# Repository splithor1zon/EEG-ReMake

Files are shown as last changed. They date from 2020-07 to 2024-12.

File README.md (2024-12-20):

# EEG-ReMake

*Accepting suggestions, just create a new issue.* 🤝

This project is based on work of OpenEEG project and Olimex's implementation of it. This project is free to use, but is bound by Creative Commons Attribution-Sharealike license. More info can be found at: <http://openeeg.sourceforge.net>

## Photos

For photos refer to [/img/README.md](/img/README.md)

## Schematics

The schematic and design files are in Autodesk Eagle file-formats. Inspired by: <https://www.olimex.com/Products/EEG/OpenEEG/EEG-SMT/>

## Documentation

I translated the original documentation and format shifted it to markdown. Documentation content list:

1. [Introduction](./doc/0_introduction.md)
1. [Theory](./doc/1_theory.md)
1. [Goals](./doc/2_goals.md)
1. [Methodology](./doc/3_methodology.md)
1. [Results](./doc/4_results.md)
1. [Discussion](./doc/5_discussion.md)
1. [Conclusion](./doc/6_conclusion.md)
1. [Literature](./doc/7_literature.md)

Please mind that this was a high school project and the documentation is not highly sophisticated. But I hope it will be of interest to you.

## The goal

The goal of this project was to customize EEG-SMT by Olimex and design electrodes producable in school environment. I tried to keep expandability of this system open by introducing few new connectors.

## Not perfect

This design definitely has its flaws, but it was tested and proved working. Using eye closing test while measuring at occipital lobe produced apparent alpha wave increase:

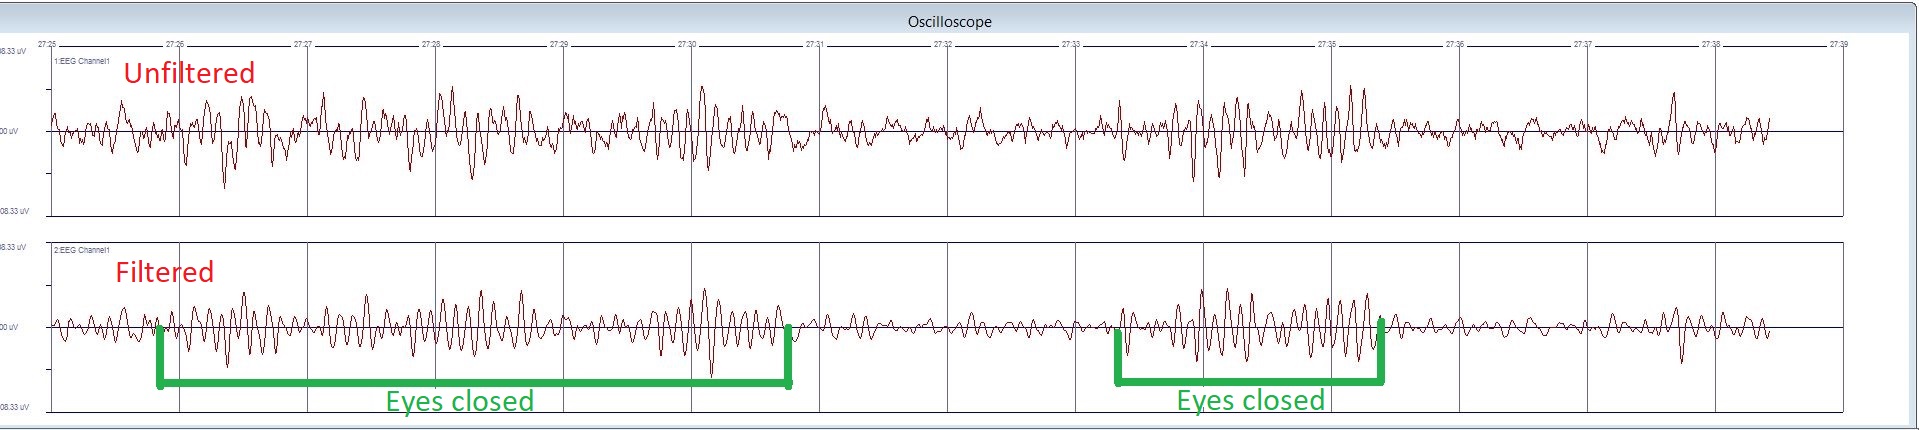
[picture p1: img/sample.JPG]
brainwave_recording Brainwave recording


## Software

As for software, I used open-source project BrainBay, which can be found here: <http://www.shifz.org/brainbay/>

## Finished Product

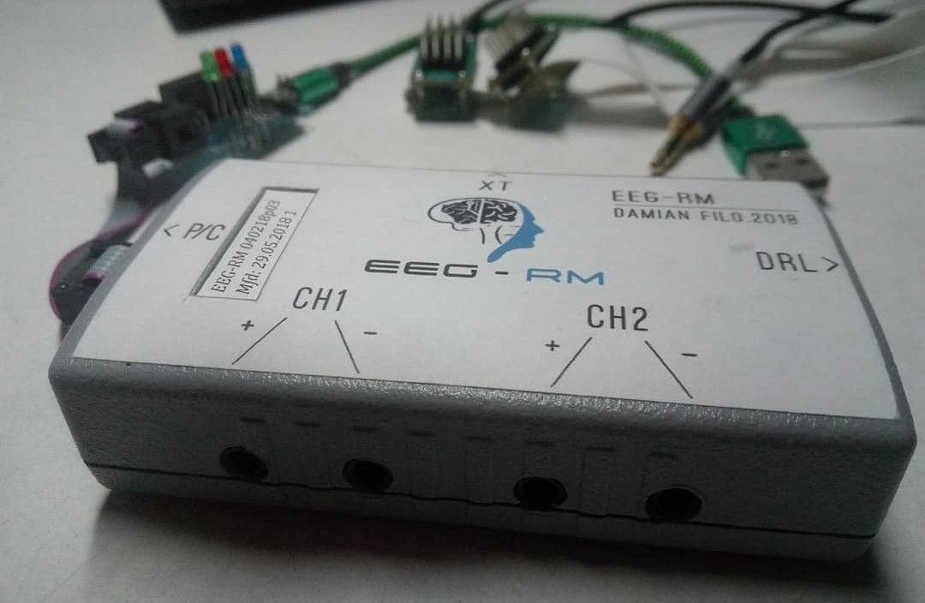
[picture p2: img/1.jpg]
Final assembly


I can also provide some guidelines on the final assembly.

## Interview about this project

<https://vedanadosah.cvtisr.sk/eeg-ako-studentsky-projekt>

Hopefully this project will help somebody. 🤗

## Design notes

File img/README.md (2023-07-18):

# Photos
Bare electrode pcb.
Active amplification electrode circuit. Assembled.
Both parts of an active electrode.
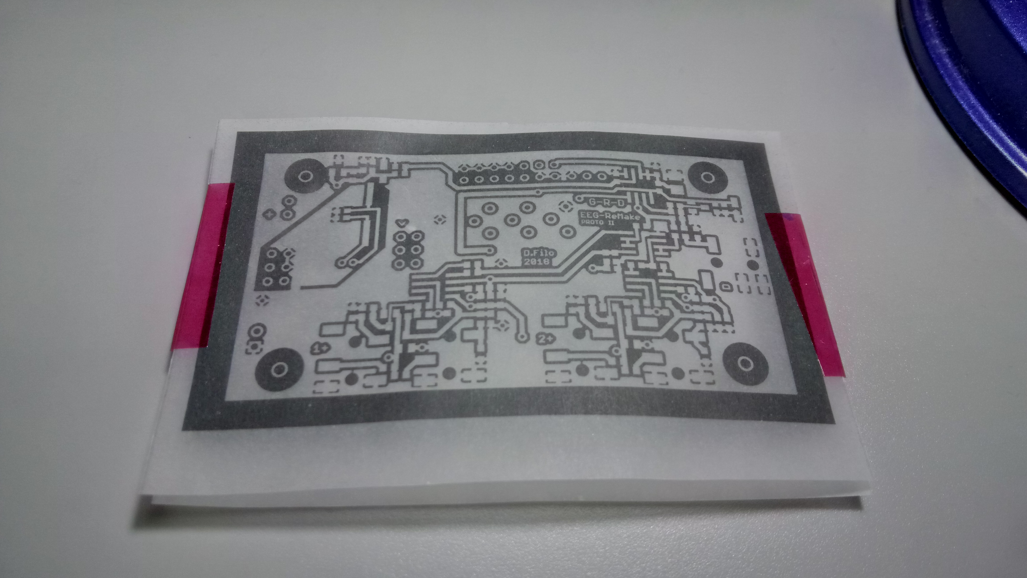
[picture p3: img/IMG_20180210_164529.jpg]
Negative of circuit board design. Blocks UV light.

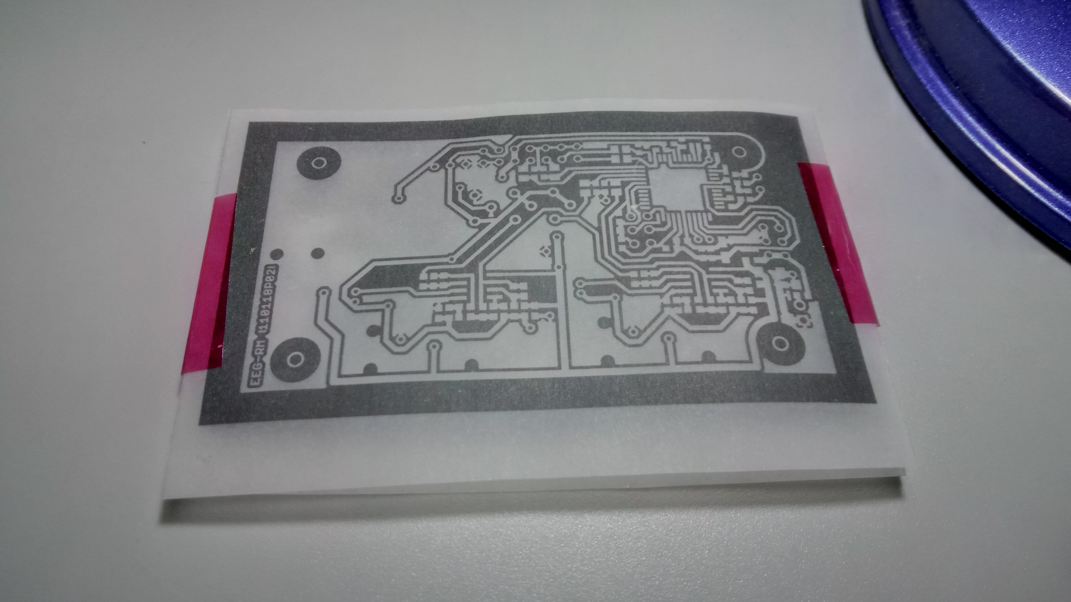
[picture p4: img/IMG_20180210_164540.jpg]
Negative of circuit board design. Blocks UV light. Other side.

Active electrode pair with rubber band head strap.
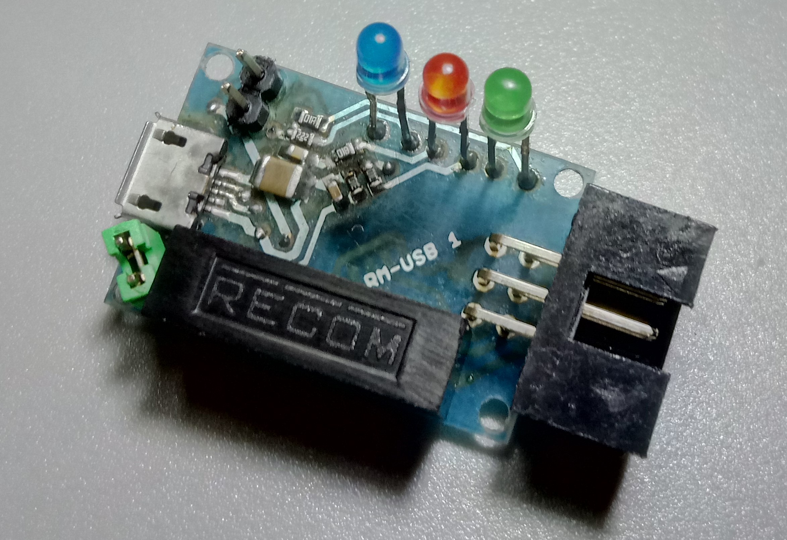
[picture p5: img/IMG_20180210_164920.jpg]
Isolated USB to UART controller. Also supplies power to the board.

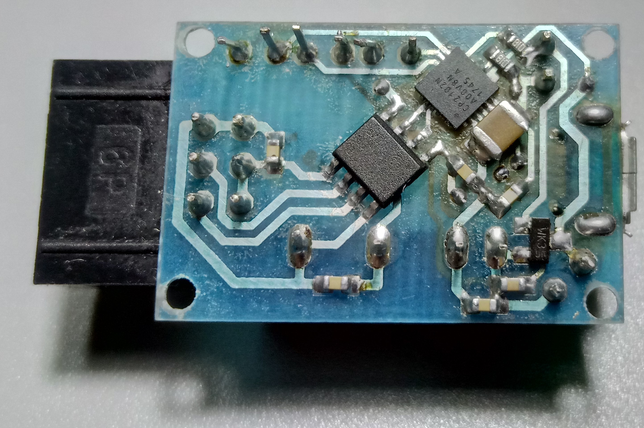
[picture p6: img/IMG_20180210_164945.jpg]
Isolated USB to UART controller. Also supplies power to the board. Other side.

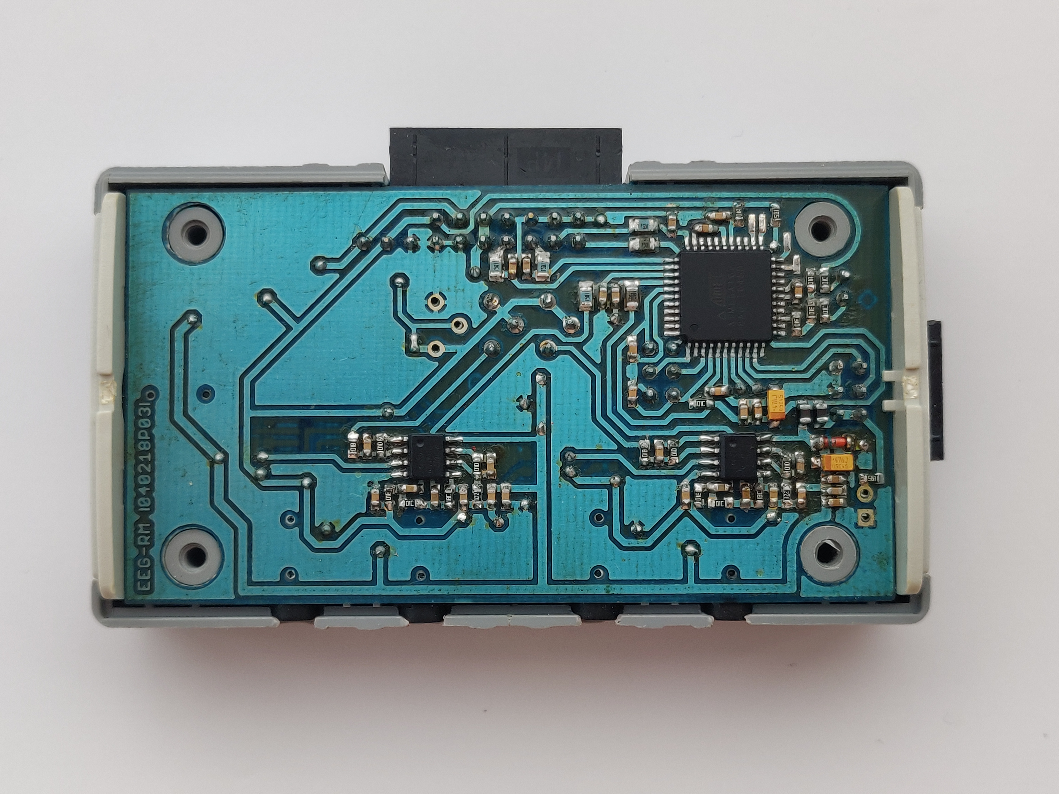
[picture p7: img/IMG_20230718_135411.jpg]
EEG board. MC side.

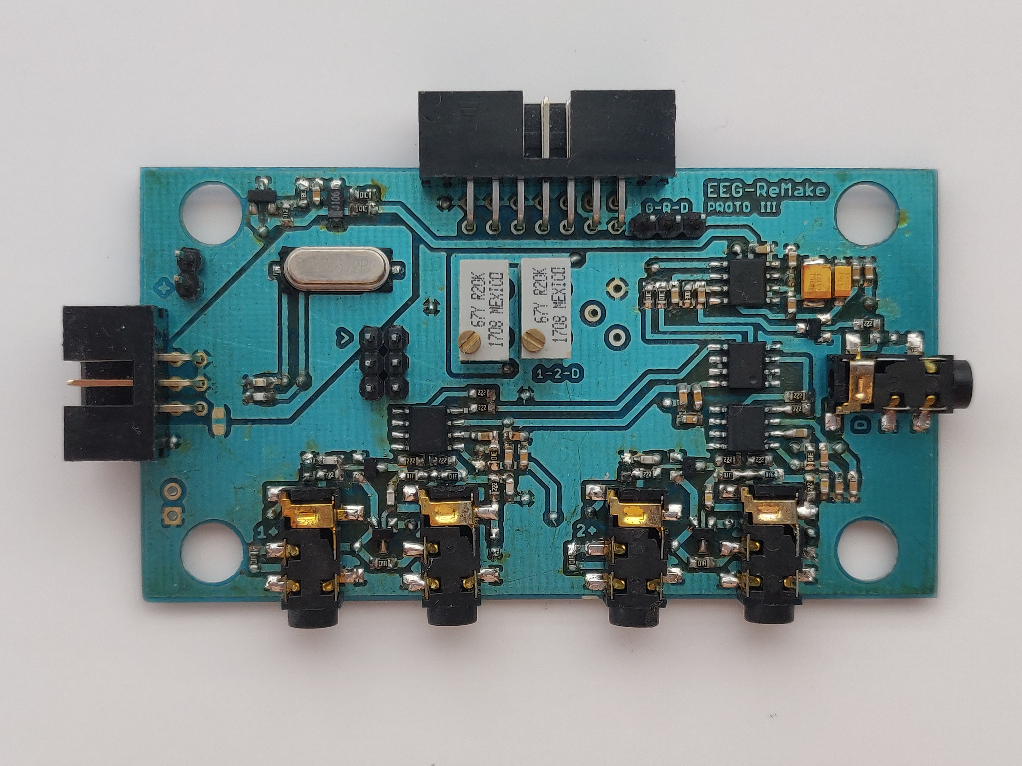
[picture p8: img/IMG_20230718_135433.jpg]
EEG board. Front side.


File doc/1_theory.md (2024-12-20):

# Theory

The electroencephalogram is at first sight a complex device, but its principles are quite simple. The average person does not encounter it every day, so it is necessary to describe the theory in detail. We should start nicely from the beginning.

## Human body (brain)

The human body, as it is known, is essentially one big electrochemical cell. It uses electrical impulses to move muscles and transmit information. Although scientists have been studying it for many centuries, it is still not understood how many things work; we can sometimes only speculate about the function of some of the components of this complex machine.

As the most important organ of our body, some of the brain's functions remain undiscovered. However, the brain is not "only" important in keeping our body alive, it houses our consciousness; without the brain as a control processor, our body would not know what to do and would be inactive. Of course it maintains important life functions, but with medical advances it is possible to keep a person alive even without brain function. In our opinion, it will not be long before the world will witness the first brain or head transplants.

Just as the whole body works on the electrochemical principle, the brain stores our memories, perceives through the senses and processes all information in the same way. While chemical reactions would be difficult for us to measure and ascertain their purpose, electricity can be manipulated by mankind in a rather advanced way. We owe the fact that we can pick up these electrical impulses in a non-invasive way to the relative conductivity of our bodies.

The number of nerve cells in the brain is estimated to be 10^11; cortical neurons are strongly interconnected. The surface of a neuron can be covered with up to 1000-100,000 synapses (the point of connection with other neurons). The resting voltage is around -70 mV and at peak action the potential is positive. The amplitude of the nerve impulse is about 100 mV and lasts about 1 ms.

## EEG

The first recording of the electric field of the human brain was demonstrated by the German psychiatrist Hans Berger in 1924 in Jena. He named the recording the electroencephalogram (EEG). From 1929 to 1938 he published 20 scientific papers on the EEG under the same title "Über das Elektroenkephalogram des Menschen".

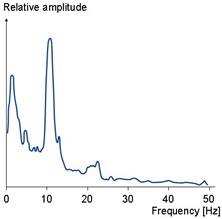
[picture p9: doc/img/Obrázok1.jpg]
"Brainwave amplitude at individual frequencies" Brainwave amplitude at individual frequencies


EEG can sense three kinds of brain activity:

1. Spontaneous activity
2. Evoked potentials
3. Bioelectrical events of individual neurons

**Spontaneous activity** is measured on the scalp "non-invasively" or on the surface of the brain "invasively". The EEG amplitude is approximately 100 μV when measured on the scalp and approximately 1 to 2 mV when measured on the surface of the brain. The bandwidth of this signal is from 1 Hz to ~50 Hz. However, individual frequencies have different amplitudes; Figure 1-1 shows the relative amplitude to each frequency. As the phrase "spontaneous activity" implies, this activity continues uninterrupted throughout a person's life.

**Evoked potentials** are those components of the EEG that arise in response to a stimulus (which may be electrical, auditory, visual, etc.). Such signals are usually below the noise level and are therefore not easily distinguishable, and it is necessary to use a large number of stimuli and signal averaging to improve the signal-to-noise ratio.

**Single neuron events** can be studied using microelectrodes that are injected into the cells of interest. Through single-cell studies, we hope to create models of cellular networks that reflect the true properties of brain tissues.

### Electrode placement

We usually use the internationally standardised 10-20 system to record spontaneous activity. In this system, 21 electrodes are placed on the surface of the scalp, as shown in Figure 1-2. The positions are determined as follows: the reference points are the "nasion," which is located at the top of the nose, level with the eyes; and the "inion," which is essentially a bony lump at the base of the skull on the midline of the back of the head.

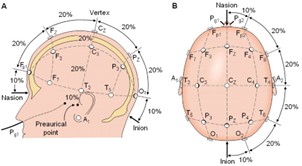
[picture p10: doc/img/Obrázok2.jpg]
"The 10-20 system" The 10-20 system


From these points the circumference of the skull is measured in the transverse and median planes. The location of the electrodes is determined by dividing these circumferences into 10% and 20% sections. Three additional electrodes are placed on each side equidistant from adjacent points, as also shown in the figures.

In addition to the 21 electrodes of the international 10-20 system, the 5-10 system, which uses a denser arrangement, is also used. There are also many other electrode systems for recording electrical potentials on the scalp. The "Queen Square" electrode placement system has been proposed as the standard for recording built-up potentials in clinical trials.

Bipolar or unipolar electrodes can be used in EEG measurements. With bipolar, the potential difference between the two electrodes is recognized. In the latter method, the potential of each electrode is compared with either the neutral electrode or the average of all electrodes.

"The difference between unipolar and bipolar EEG" The difference between unipolar and bipolar EEG

### The sources of EEG signal

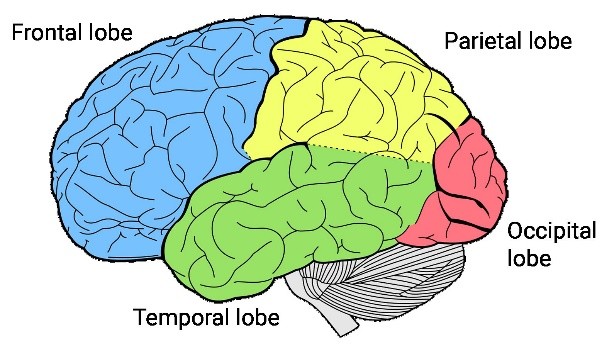
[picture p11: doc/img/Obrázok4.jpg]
"Brain lobe locations" Brain lobe locations


In the figure above you can see how our brain is divided into different sectors. Thus, when the EEG senses the time course of electrical activity generated by the brain, we can capture specific waves of our interest because we know approximately which areas of the brain are responsible for processing information at any given time:

**Occipital lobe** - This part of the brain is mainly responsible for processing visual information. It is usually where we measure the reception of visual stimuli (video, pictures).

**Parietal lobe** - The parietal lobe is very important in processing sensory information from different parts of the body, knowledge of numbers and their relationships, and manipulation of objects. Its function is also to process information related to the sense of touch. A part of the temporal lobe deals with spatial vision.

**Temporal lobe** - The temporal lobe has external parts that are responsible for language processing and speech production. The inner regions are more active during spatial navigation. You may have heard of the hippocampus: This is the brain region in the temporal lobe where we form spatial and autobiographical memories from, for example, early childhood days. It is also referred to as the primary area for auditory processing.

**Frontal lobe** - The frontal part of the human brain is enlarged compared to other mammals. Basically, the frontal cortex is in charge of cognitive control: it keeps us from running after flashing lights, forces us to complete studies, and connects different memories and experiences into a consistent whole. In other words, we are able to move voluntarily thanks to it, to make simulations of the future and simulations of the consequences of our actions (to decide between good and evil).

### The structure of EEG signal

In addition to the area characteristics from which certain electrical activity originates, we can also analyze which frequencies drive the ongoing activity. Whenever our brain is in a certain state, the frequency patterns change.

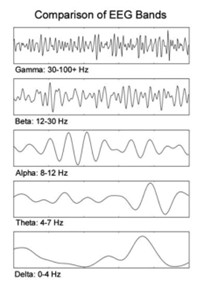
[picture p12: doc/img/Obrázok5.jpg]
"Comparison of EEG bands" Comparison of EEG bands


**Delta δ (1-4 Hz)** - In sleep labs, delta waves are studied to assess the depth of sleep. The stronger the delta rhythm, the deeper the sleep. Interestingly, delta waves are only present in non-REM (Rapid Eye Movement) phases - when we are not dreaming, for example.

**Theta θ (4 - 8 Hz)** - Theta is associated with a wide range of cognitive processes, such as encoding and memory retrieval, but it depends on the area.

**Alpha α (8 - 12 Hz)** - Alpha waves can be observed mainly when relaxing with eyes closed. EEG training often uses alpha waves to monitor relaxation.

**Beta β (12 - 25 Hz)** - Commonly seen in people with normal waking consciousness. In motor areas, beta frequencies become stronger when we perform or plan to perform movements of any part of the body. Interestingly, this increase in beta is also noticeable when we observe other people's body movements. Our brains seemingly mimic the movements of their limbs, suggesting that there is a complex "mirror neuron system" in our brains that is coordinated by beta frequencies.

**Gamma γ (>25 Hz, typically 40 Hz)** - Currently the gamma frequencies are the black holes of EEG research. Some researchers argue that gamma reflects strong concentration and serves as a carrier frequency to facilitate data exchange between brain regions. Others associate gamma with rapid eye movements, the so-called "microsaccades," which are thought to be essential parts for sensory processing and information capture.

EEG also has a great use in medicine, mainly because it can detect epileptic seizures that whether a person is susceptible. EEG in epileptic seizure records unambiguous regular pulses with high amplitude, as you can see in the picture. However, we know many types of epilepsy and their EEG may look different, however most of the time it is easily detectable.

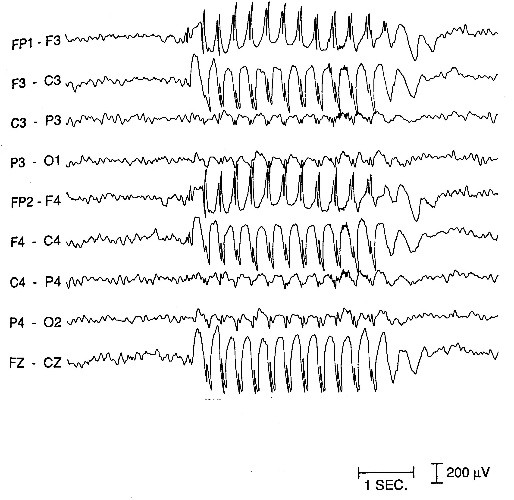
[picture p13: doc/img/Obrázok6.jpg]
"EEG during epileptic seizure" EEG during epileptic seizure


## Hardware

Electroencephalographic measurements use a recording system consisting of:

- electrodes (usually with conductive media)
- amplifiers and filters
- A/D converter
- recording equipment

The electrodes read the signal from the surface of the head, the amplifiers transmit the microvolt signals to a range where they can be accurately digitised, the transducer converts the signals from analogue to digital form, and personal computers (or other relevant equipment) store, process and display the acquired data. The amplifiers with filters and the A/D converter are usually housed in a single device called a BCI (Brain-Computer Interface). The main intention of this work is to create this device.

The best way to explain this is to use the device itself, so I give examples of the components we will use, although there are many other variations.

### Electrodes

In our device, we will use so-called active electrodes, which, because they amplify the signal as soon as it is recorded, will not be so susceptible to signal interference on the way to the amplifier. We don't have to worry that the electrodes will be big because of this, of course they will be bigger than passive electrodes, but with a low number of channels it doesn't matter at all. Our EEG will be expandable up to 6 channels in a bipolar circuit, that means 12 electrodes plus 1 DRL for connection. This is a decent expandability in our opinion. The active electrodes we will make will be only 14x22mm, will be able to penetrate through the hair directly to the skin using pins, and can also be clamped on a rubber band for attachment to the head. Active electrode construction developed by us:

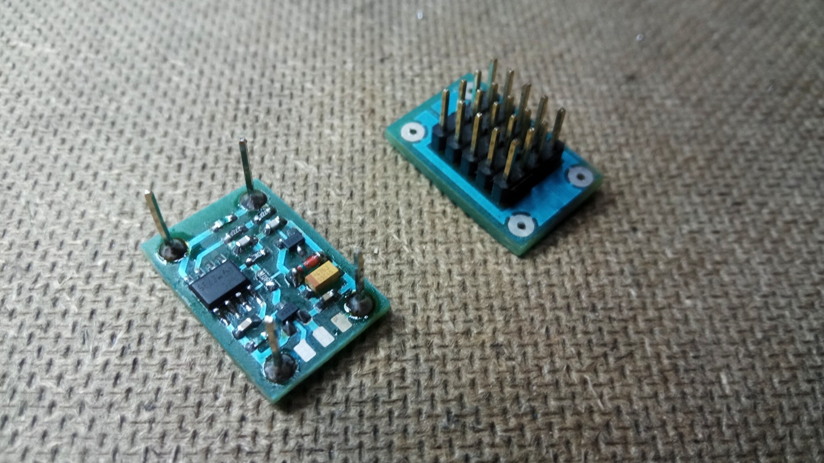
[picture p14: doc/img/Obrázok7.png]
"Active electrode with contact and active part" Active electrode with contact and active part


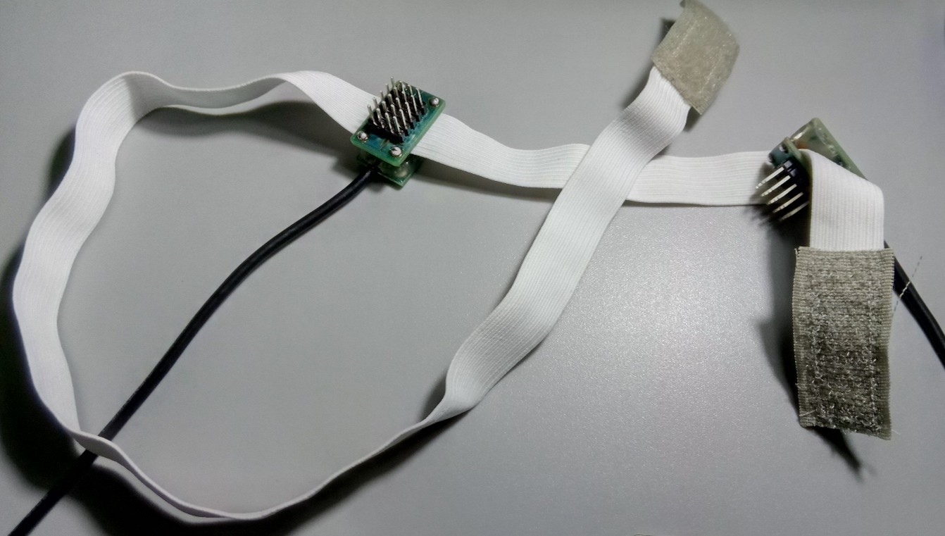
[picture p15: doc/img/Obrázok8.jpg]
"Assembled pair of electrodes with head strap" Assembled pair of electrodes with head strap


The DRL (Driven Right Leg) electrode is very important because it picks up a reference signal from some neutral location on our body and subtracts the recorded signal from all channels. This way we largely eliminate interference from the surroundings and our own body. The DRL electrode must be passive because the use of an active electrode would not allow it to function properly. Reference DRL wiring:

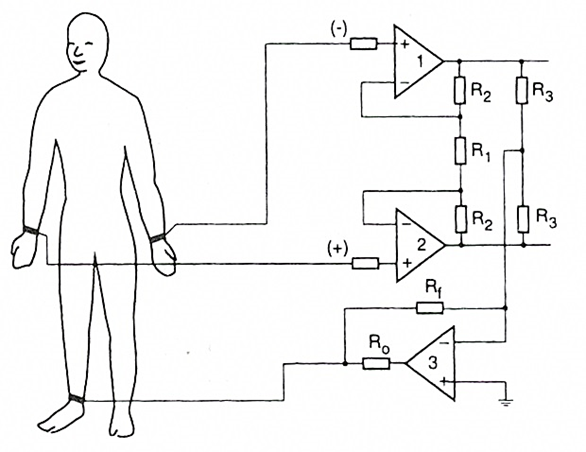
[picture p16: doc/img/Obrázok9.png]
"DRL electrode design" DRL electrode design


The length of the electrode cable is critical at such small voltages, generally a length of around one metre is recommended for the device we make. We use 3.5mm jacks to connect the electrodes to the BCI, but this is specific to each type of device separately.

### Amplifiers and filters

The first amplification stage in our device is located at the active electrodes. The captured and slightly amplified signal then travels to the instrument itself, where it is the turn of the instrumentation amplifier, which is basically several operational amplifiers specially interconnected in one package. It has a dual function, to read out the captured signal of the DRL electrode and to accurately amplify the as yet very weak signal.

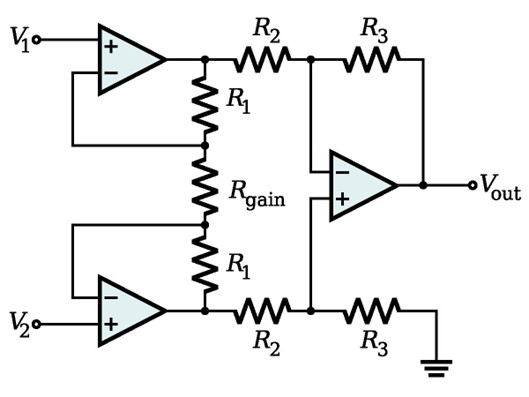
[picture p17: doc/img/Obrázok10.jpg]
"Instrumentation amplifier diagram" Instrumentation amplifier diagram


Next comes the dual operational amplifier, which also performs a dual function. The first serves as a trimmer-adjustable gain control to calibrate the signal amplitude. The second serves as a third-order Bessel-type low-pass filter, i.e. it "cuts off" all frequencies above 152Hz. This is a very beneficial effect, since we need frequencies in the 1-50Hz range and all other frequencies are simply interference. Interference from either the mains or other electronic equipment is usually removed or attenuated by the DRL system already in use.

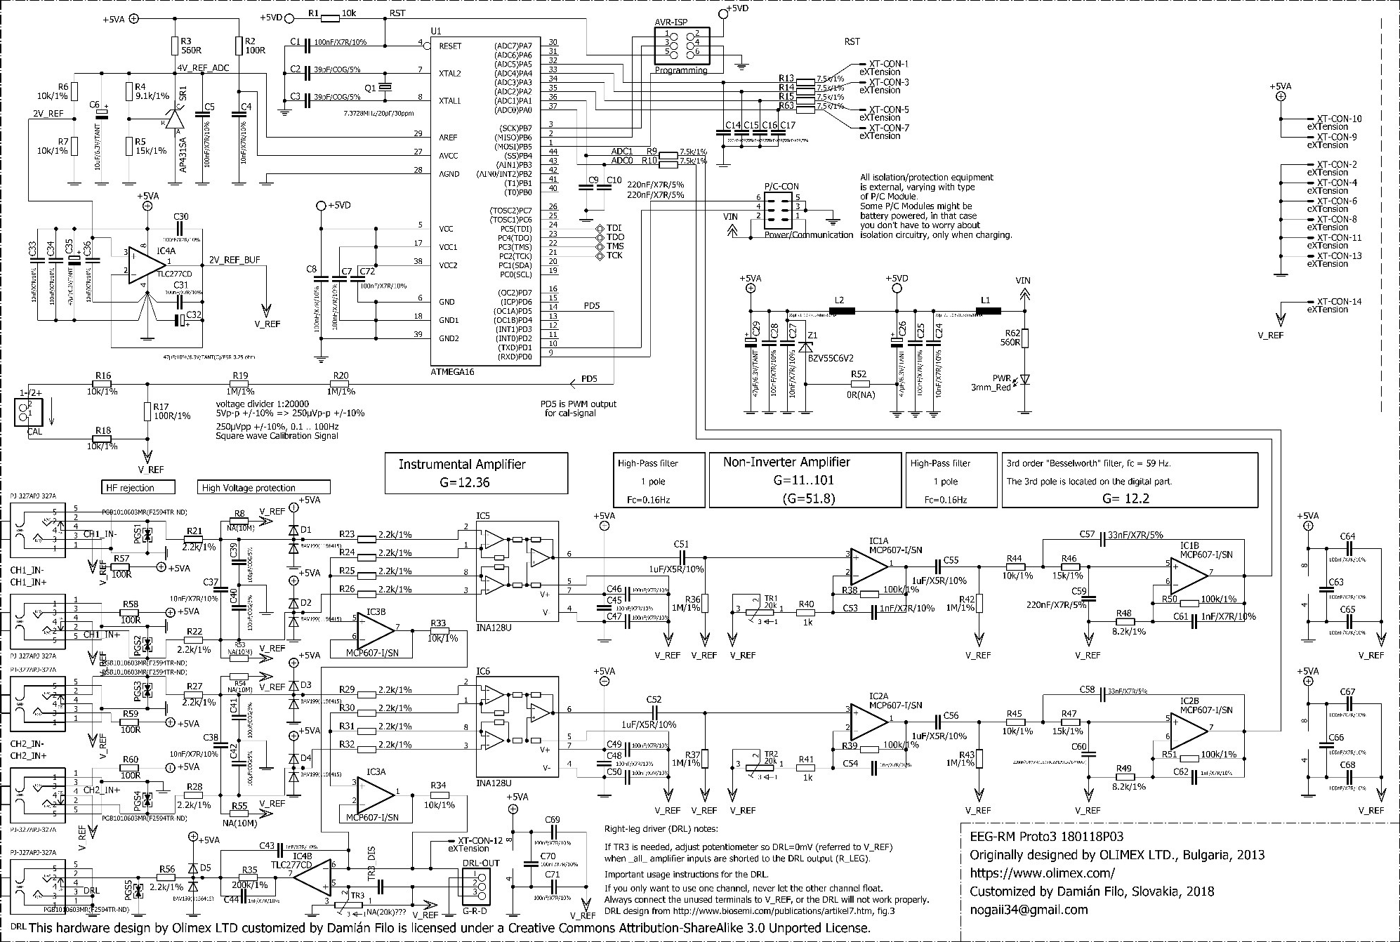
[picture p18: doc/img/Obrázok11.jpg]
"EEG circuit scheme" EEG circuit scheme


The basic gain after all these stages should be G=7812.5, which can be further tuned. The passband filter should be in the range 0.16-152Hz.

### A/D converter

It is an integral part of the whole device that allows us to view, record and edit the signal on digital devices, not just on the oscilloscope. The output from the amplifier cascade terminates on one of the pins of the A/D converter, in this case in the form of an ATMega16 microprocessor. We use a sampling resolution of 10 bit i.e. 1024 possible values on a 0-4V scale. This, after subtracting the gain, gives a range at the input of 512µV at 0.5µV resolution. Since the captured signal is in the region of 100µV this is adequate.

### Recording device

Once the signal has been successfully digitised, we need to send that data on for processing. The best way to do this would be to use a universal form of connection to computing and what is more universal than a universal serial bus (USB).

The ATMega16 microprocessor somehow does not support USB connectivity, but it can send data via UART (universal serial communication). Although UART is not directly compatible with USB, there are a number of chips from different manufacturers that can interconnect them. I decided to go the modern route and use the latest chips from Silicon Labs. The CP2102N chip offers more than enough data throughput, a wide range of features in a small form factor and at a reasonable price. Reliability was also a critical factor.

However, since we decided to use power directly from the USB interface, it is necessary to isolate our device from the surrounding environment for safety. We achieved this by using an isolation 5V-5V DC-DC converter for the power supply and a chip to isolate the data connection also from Silicon Labs.

Due to the modularity of our device, this USB/UART converter will be able to be used in applications other than EEG. The reverse is also true, it is possible to create arbitrary interfaces using e.g. Bluetooth technology, where we ensure complete isolation from the environment when powered by the battery.

Thanks to the IDC connectors used, modularity is easy, no special connectors, all one needs to know is the pin layout.

### Software

We decided not to spend a lot of time on software because of the open-source solutions that already exist. However, that doesn't mean we don't need to spend time on it at all. We plan to create simple software in the future designed to control the EEG power supply.

We will use "BrainBay" as the main program to display and process the EEG data. But in general, we can use any program supporting OpenEEG packet composition version 2. The interface of this program is quite simple and user-friendly. It supports signal acquisition from multiple sources and a wide range of modifications to these signals. On the output we can display a digital oscilloscope, frequency analyzer, MIDI synthesizer, visualization, various graphs, columns and much more. This program also supports logging of the acquired data.

[Next page](./2_goals.md)

*Translated by DeepL.*

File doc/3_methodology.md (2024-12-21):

# Methodology

The methodology will be written in a way that any electronics enthusiast with more advanced knowledge and experience of PCB fabrication and component assembly can understand.

## Open-source licensing

We decided to go the route of an open source project, as it would have taken us months if not years of focus to build a schema from the ground up and test the wiring.

The OpenEEG project was exactly what we were looking for. Not only did a group of enthusiasts create a schema and a way to get involved, but they also created a community. While it's true that this project is older (~2005) and fewer and fewer people refer to this project, if we had a question about the project, there was always someone who could help us via email.

This project is licensed under a Creative Commons Attribution - ShareAlike license. This means that this project can be used and shared without restriction as long as the source is credited and the same license is used. I plan to share this iteration of the project once I have completed the design and schematic. Definitely sounds interesting to contribute to such a great community of enthusiasts. Hoping that our work will help someone who may be doing a similar vintage project, well that's the future...

Although we're not using the original ModularEEG project, but an iteration of it optimized for direct USB connectivity, compact size, and use of SMD components called EEG-SMT. I can and must stick to the original license. This iteration was made by Olimex Ltd, a Bulgarian company based in Plodiv, Bulgaria's second largest city. This company sells parts and finished electronic projects. And thanks to that license, it was necessary for them to also share their schematics and PCB designs, which we customized. The modified schematic:

"EEG circuit scheme" EEG circuit scheme

## Component selection

Since Olimex has access to a quasi-limitless amount of those specific parts, we didn't have that option. We used various sites as sources of parts, such as AliExpress for connectors and cables, where you can get such parts cheap and of good quality. For the rest of the functional parts (resistors, capacitors, integrated circuits...) we used the Mouser site, where they have a very wide selection and free shipping for orders over 50$. Later we had to reorder some parts through a friend because we made some changes in the design. The lesson learned was: Order only the final selection of parts, think carefully.

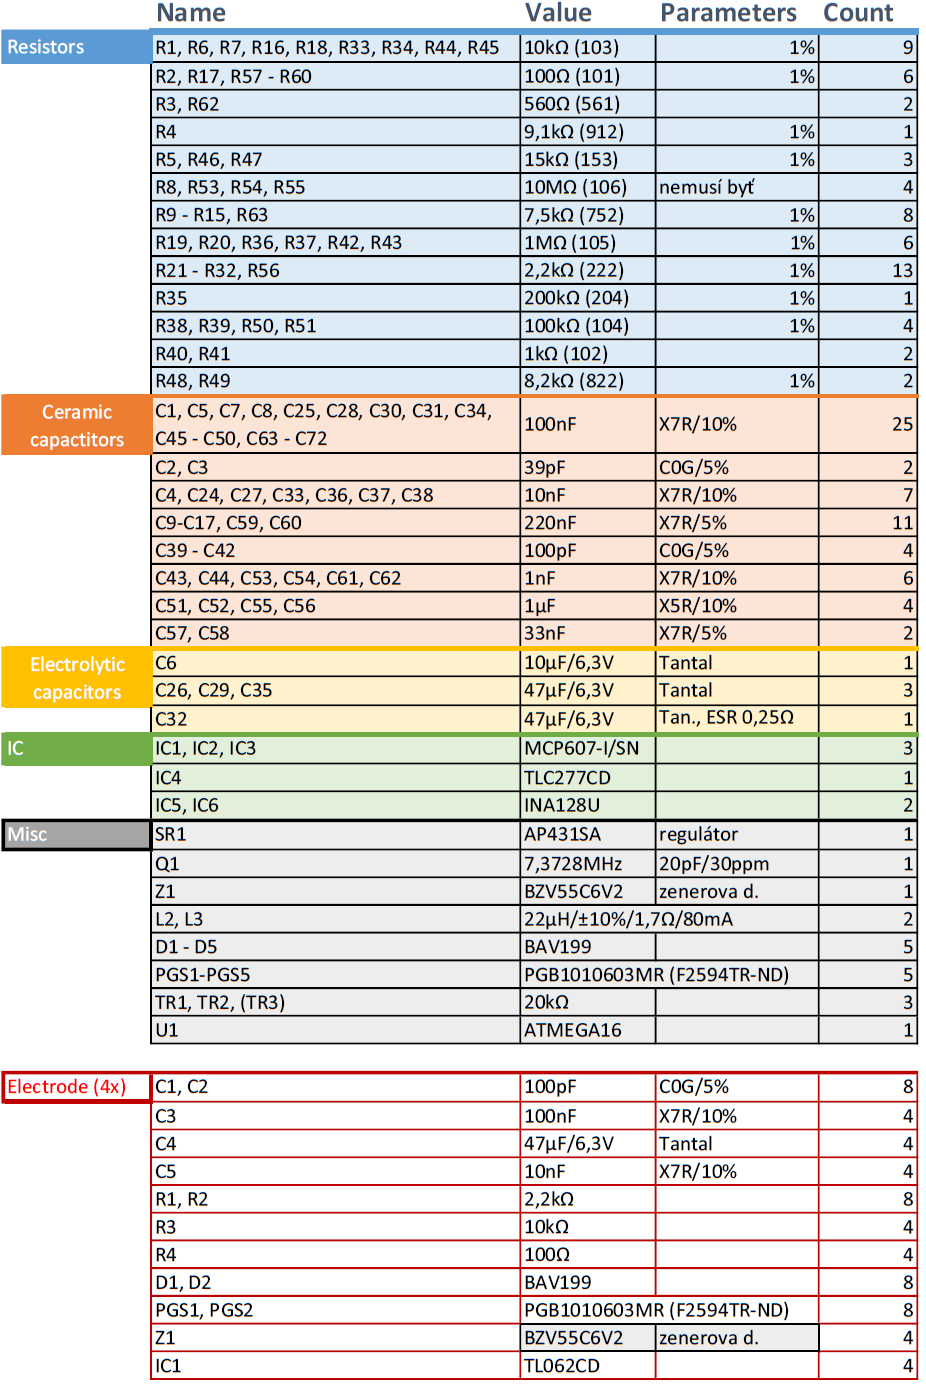
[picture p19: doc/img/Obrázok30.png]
"Component list"


## First prototype

This was our first experimental design on which we honed our skills with Eagle. It took us at least 3 weeks to modify the schematic and design the PCB. That's not counting the actual product. However, it was accompanied by a few complications, which fortunately were solved "painlessly". For etching I used a solution of hydrochloric acid and hydrogen peroxide.

The first complication was insufficient silver plating of the PCB, this translated into insufficient adhesion of tin to copper, which corroded due to the environment. Being silver plated, the tin spilled out seamlessly. Although there was a higher risk of a cold joint (electrically non-conductive), it was possible to solder all the components together.

The other not-so-big complication was using smaller SMD parts (0603) than I used in the design (0805). This had the effect of reducing the neatness of the PCB and making it more difficult to store and solder the components.

The third, rather unpleasant complication was the very imperfect etching, soldering and fixing of the MicroUSB connector located directly on the board. It had to be in a specific position for it to be used at all. Since Prototype 1 also had an IDC connector for power and communication, it was only meant at the time as an I/O for data and an output for power. Thus, MicroUSB held the main role of powering the circuits and had no data pins connected. Later, after re-evaluating the pros/cons, we decided to merge it with the IDC connector and thus called it Power/Communication Connector (P/C CON) to which the P/C Module connects. It acts as a power supply to the EEG and communication with surrounding devices (depending on the module used).

The fourth complication was the inexperience of programming ATmega microprocessors. When first programmed and connected to the computer, the EEG sent nonsensical data. Upon later discovery we found out that it only worked on an internal clock of 1MHz, This caused insufficient data processing speed and slow data sending. As we are using UART technology and within it we need to choose a fixed baud rate as a requirement for correct communication between devices. The crystal of unconventional frequency of 7.3728MHz guarantees the correct frequency of sending data through UART, where it is allowed to multiply/divide this frequency for our requirements. The simple solution to this awkward situation was to set the configuration fuses correctly during programming. This allowed us to activate the external crystal and use its frequency.

Although we were unable to test Prototype 1 with electrodes, due to the swapping of the power and signal pins in the jack used in the wiring in Prototype 2, overall Prototype 1 can be called a success. Its schematic, photos and design can be found as attachments. The design of the first prototype:

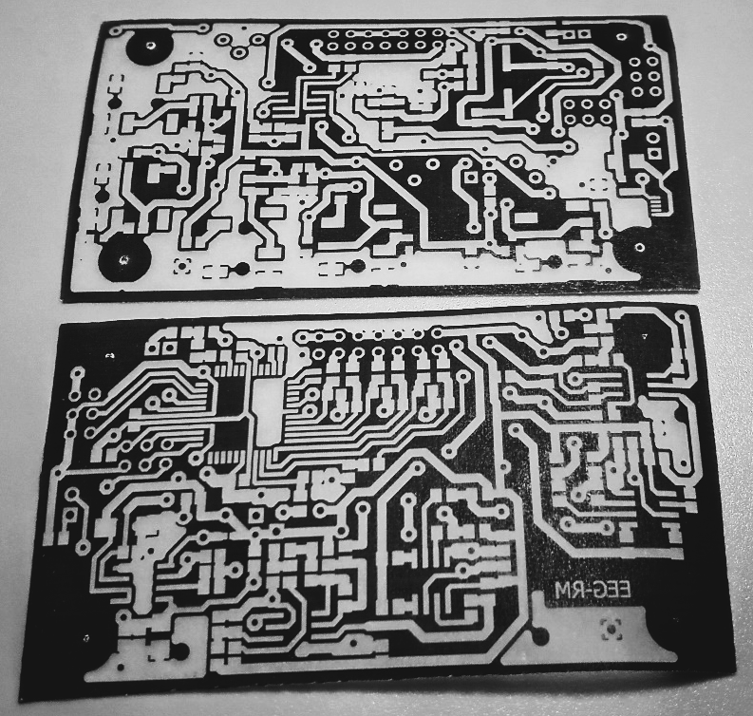
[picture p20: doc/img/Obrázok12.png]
"First prototype PCB design" First prototype PCB design


## Electrodes

The biggest challenge in designing the electrodes was figuring out their construction. We were very interested and inspired by the work of Jim Peters, who invented the design of electrodes with a contact surface consisting of pins. The pins allow the electrodes to be connected to the head even through the hair and the fact that they are also active makes it possible not to use a conductive gel, which can though still be beneficial. Olimex has provided a reliable and safe circuit design for these electrodes, however they only sell electrodes with a contact area directly on the gold plated surface, i.e. it is necessary to use a conductive gel for contact with the skin through the hair. We did not modify the electrode scheme in any way, but we did our own construction design and devised a method of firmly connecting the pins with the possibility of clamping the electrodes to a elastic band with Velcro for easy and firm fitting of the electrodes to the head.

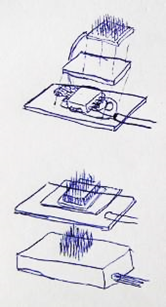
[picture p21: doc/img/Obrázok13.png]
"Jim Peters's electrode design" Jim Peters's electrode design


Our design of the active electrodes consists of two circuit boards, one designed explicitly for the pin connections and the other containing all the electronic components and pads for connecting the audio cable to the power supply for the operational amplifier and transmitting the signal to the EEG itself. These two PCBs are firmly soldered together using four solid brass pins located around the corners of these PCBs of identical size 14x22mm. Of these, one pin transmits the signal from the pins connecting to the skin to the other PCB where it is amplified and sent on.

"Active electrode with contact and active part" Active electrode with contact and active part

For easy placement on the rubber band, also easy movement on it and protection of electrical components we sealed the circuit with glue from a glue gun. This makes these electrodes the final product and suitable for use in any ModularEEG type EEG with the correct connection of the individual wires in the cable. The 3.5mm jack does not have to be used, but it is very suitable for this purpose, due to its widespread use, portability, reliability and above all the five pin female connection method, which I have only used in the third prototype. In short, it allows not to use all the electrodes while maintaining the correct functionality of the DRL, since the DRL needs to have all the electrodes connected to the body, they cannot remain unconnected (so called float). The usual method is to connect additional signal jumper cables to the V_REF virtual ground, however these female jacks allow automatic connection to this ground. Thus connecting when the electrode is not connected and of course disconnecting when the electrode is connected. The idea for this wiring was suggested to us by Stefan Jung, who emailed us asking for troubleshooting and understanding the functions of the various components of this particular EEG.

"Assembled pair of electrodes with head strap" Assembled pair of electrodes with head strap

The procedure for their manufacture is quite straightforward and can be found in pictorial form as an appendix. We would only note that you have to be careful about the rotation of the components as well as the PCBs, because they are not symmetrical and can only be joined together with one side, one direction. Also, we do not recommend a cable length greater than 1.2m, as in similar designs cables around 2m long have shown malfunctions that are incompatible with the correct function of the device.

## Second prototype

Overall, Prototype 2 is a very neat and professionally done design. In addition to the radically different placement of components, the swapping of pins in the electrodes, and the removal of the MicroUSB connector, there are changes such as bringing out the control pins for electrode calibration and for DRL connection configuration and diagnosis. Further, the dimensions of the PCBs were sized exactly to the components used, a better power cascade and ground polygon, lettering for easy identification of the brought out pins, female jacks and trimmers on the board, a reduction in the number of interconnects through the PCB, the product name changed from the original EEG-SMT to EEG-RM (ReMake), and a simple serial number consisting of the date and version of the prototype was added. The already etched clean unmounted PCB of the second prototype:

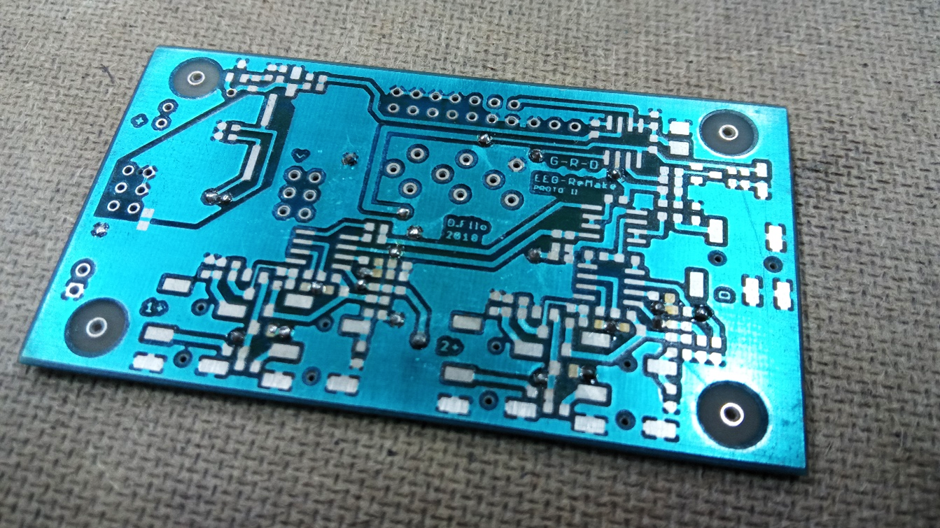
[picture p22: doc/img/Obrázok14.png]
"Front side of Prototype 2 PCB" Front side of Prototype 2 PCB


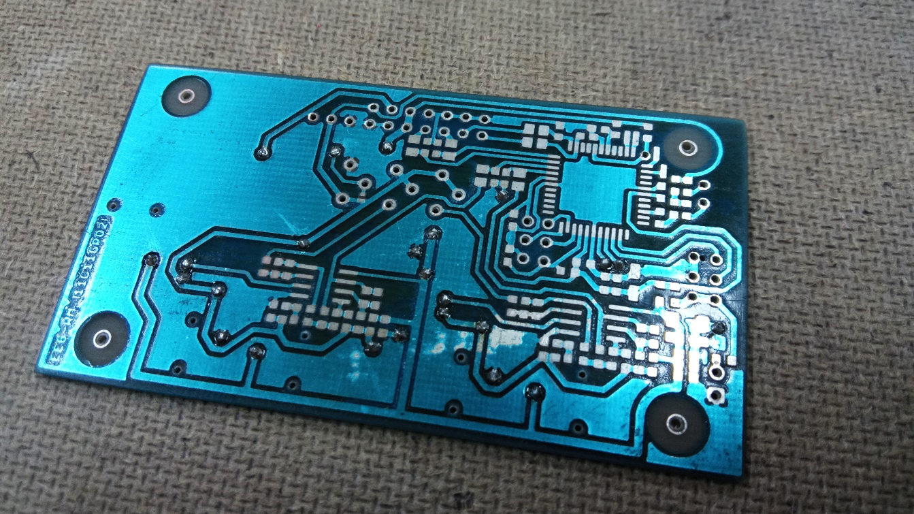
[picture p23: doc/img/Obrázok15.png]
"Back side of Prototype 2 PCB" Back side of Prototype 2 PCB


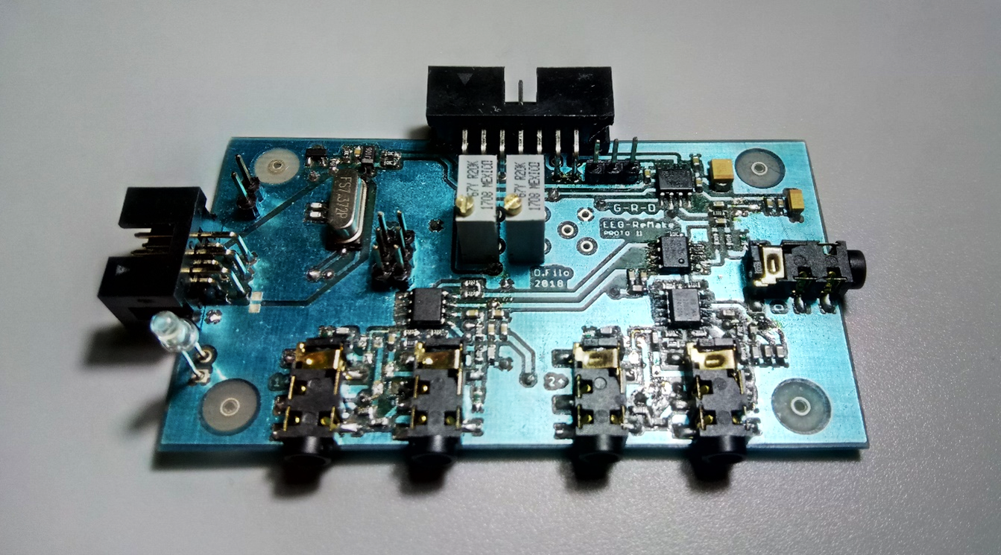
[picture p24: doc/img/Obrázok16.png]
"Front side of Prototype 2 PCB with components soldered on" Front side of Prototype 2 PCB with components soldered on


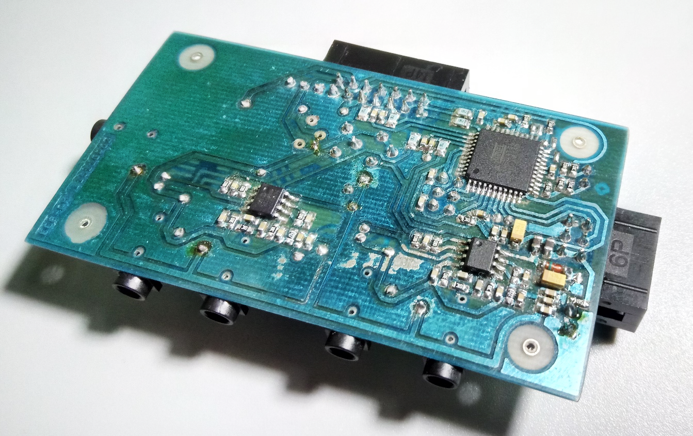
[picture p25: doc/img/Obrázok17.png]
"Back side of Prototype 2 PCB with components soldered on" Back side of Prototype 2 PCB with components soldered on


The big change was to combine the power and communication functions under one connector, the P/C connector. This original connection using the IDC 6pin connector allows you to create a set of P/C modules differing in the technologies used, power and isolation options under one universal connection method. We have placed emphasis on ensuring that incompatibilities do not arise in the future. In this way, compatibility is more or less guaranteed. Whether one uses wireless or conventional technology, as long as that technology can interpret UART, which is a very widespread and universal connection standard, there will be no problem with connectivity and application development.

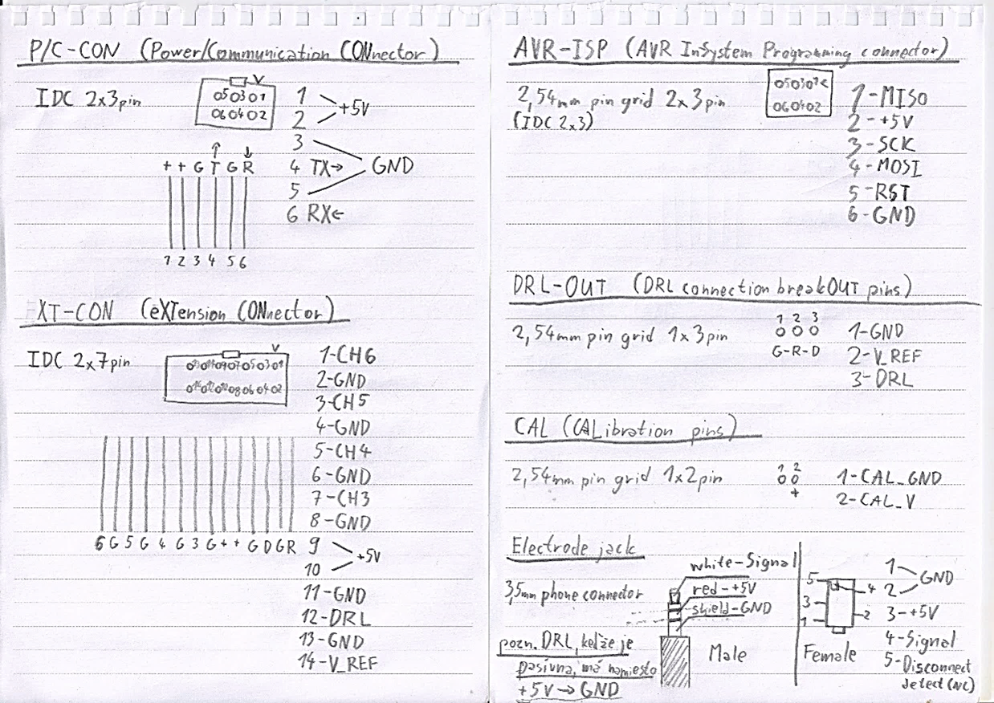
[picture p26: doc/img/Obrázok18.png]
"Interfaces of the EEG device" Interfaces of the EEG device


"P/C USB UART module version 1 top side" P/C USB UART module version 1 top side

"P/C USB UART module version 1 bottom side" P/C USB UART module version 1 bottom side

This release was supposed to solve all the shortcomings of prototype 1, but complications arose and due to our inattention it was not functional at first. (Version 110118P02)

The first error occurred in Eagle, where we needed to update the libraries and unfortunately that update switched the pads on the BAV199 protection diodes, causing a short circuit. Because the BAV199 diode has three pads to which it has two diodes connected in one direction: pass direction, center and stop direction, respectively. The confusion of plates 1 and 2 caused a theoretical short circuit between 5V and GND. By routing the 5V power supply through the individual junctions, it was easy to identify the source of the problem, but we unexpectedly discovered another problem. The turning of IC3, which more or less was in short circuit as well. The solution to this problem was to desolder the diodes and unsolder the integrated circuit, turn it over and re-solder it.

"BAV199 diode diagram" BAV199 diode diagram

The communication with the computer was flawless, but the problem occurred only after connecting the electrodes to the head and especially the DRL electrode. Our signal, which consisted (at least) of an interference signal, completely disappeared or made no sense after connecting the DRL. We suspected the IC3 (part of the DRL circuit), due to the fact that we had inadvertently reversed it and a very large current was flowing through it. In the end, however, it turned out that we had just forgotten to connect the two pins intended for this in case we didn't use the tuning trimmer for the DRL. After connecting those pins, the EEG worked as it should.

The next logical step is to modify this design to correct the deficiencies that have arisen and, if necessary, to rethink the layout of the components once more. In version 170118P02, we corrected the diode wiring, but decided to make further, mainly cosmetic changes, which translated into prototype 3.

## Prototype 3

This version is not that different from the prototype 2, but it brings some mainly cosmetic changes and modifications to a few roads. Most of the changes are to the IC4 and the components around it. The trimmers are shifted. The crystal is rotated 90°, for easier fitting. Naming and names are relocated, optimized for their nicer etching. This is found in version 180118P03. The PCB layout and connections without ground fill:

"Top view of prototype 3 PCB" Top view of prototype 3 PCB

"Bottom view of prototype 3 PCB" Bottom view of prototype 3 PCB

The 040218P03 version has in addition to this the already mentioned automatic disconnection/connection of the signal inputs to the amplifier to ground, necessary for the correct functioning of the DRL. This is basically the latest version of the EEG-RM, which has aspirations to become the final version.

"Complete system" Complete system

[Next page](./4_results.md)

*Translated by DeepL.*

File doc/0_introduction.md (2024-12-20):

# Introduction

Each of us sometimes wonders what's going on in his head, how his brain works. The function of the brain is very fascinating and it would be interesting to explore it. The year-long project provided us with the space and helped us in the realization of our idea, to build an electroencephalogram. (EEG for short). Since EEG uses a non-invasive sensing method and we can build it relatively easily, it was an obvious decision. Although our field does not have a primary focus on electrical engineering, our fascination and fondness for it allowed us to build modified and improved open-source hardware for our needs. As fascinating as it can be to create EEG-controlled software, we decided to make the device itself primarily reliable and practical. Since open-source programs exist in a wide variety and the first priority was to procure the hardware.

Buying a ready-made EEG is an option to get a reliable and proven device, but building it is a challenge and the price ratio between bought and built is abysmal. The unaffordability of the EEG does not allow its easy dissemination especially for educational purposes, not only to medical students. One of the aims of my project is that it is possible to construct a multi-channel EEG even with electrodes with a price tag of under a hundred euros. Not to mention that classical medical EEG uses passive electrodes, with the need to use a conductive gel for a perfect connection with the skin. That's not very nice when you have to wash off the gel after each use... We decided to create active electrodes that, with the help of pins, can pass through the hair and touch the scalp while amplifying the detected signal. All this in a compact size.

If all this works, we will create an expandable, modular, compact, reliable and relatively inexpensive device for measuring brain waves in school settings.

[Next page](./1_theory.md)

*Translated by DeepL.*

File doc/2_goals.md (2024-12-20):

# Goals

The primary goal is the most important one, to build a working EEG hardware (BCI). However, there is quite a long way to go. First of all, you either need to find all the necessary theory and invent the circuitry completely from scratch, or find an open source project that you can modify to suit your needs. If we get one or the other, we can start making a first prototype on which we can test the functionality, or fine-tune certain parameters. The road to the first prototype is a winding one, we need to think first what we actually need, what connection methods, number of electrodes, customizability...

As long as we think about all these parameters, we can start making a schematic in some CAD program, in which we can also directly create the PCB design. The logical step after designing the PCB and selecting the appropriate components is to purchase these components and manufacture the PCB.

Here comes the most stressful part, the functionality testing. As long as the first prototype is functional, there won't be much to change, but there will always be some beauty bug or change in the size of the parts.

That way it's already time for prototype number 2 and also the possible final version. Modification of the PCB, better selection of components... But after this journey, the aesthetic side of this product will also have to be taken care of. Getting a box of adequate dimensions, prioritizing neatness over speed when soldering, making a print and proper labeling for ease of use. All of this will give the effect of perfection to this product.

The next step is to design and manufacture the modules for connection to the recording equipment. For which we need to think about isolation from the environment and power supply.

[Next page](./3_methodology.md)

*Translated by DeepL.*

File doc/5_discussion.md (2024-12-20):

# Discussion

Initial testing of an already functional product was very interesting. There are many ways to test it. However, we chose the most obvious and most used: the eye-closing test (waking alpha rhythm). It was interesting to see how the invisible brain waves in the occipital lobe change based on whether our eyes are closed or open, whether we are in a level of relaxation or not...

"EEG recording with eyes closed test" EEG recording with eyes closed test

Speaking of the occipital lobe, measurements of built up potentials, e.g. looking at a fixed flashing screen, must be very interesting as well. In this type of signal recording, averaging the signal and looking for deviations is very important, as these potentials are often overwhelmed by interference and "looking" for deviations is necessary.

Structurally, this product has succeeded, it can be fitted into a box and called self-made. It wasn't easy, but the journey was worth it. When one sets a goal, no matter how challenging, if one puts in adequate effort, one is destined to succeed.

The hardest part comes after that. The practical applications are wide and that is why it is difficult to find any ideal type of measurement. Different purposes - different requirements. Integrating real-time data analysis into the application of this equipment is not easy and can be inaccurate. However, thanks to the modularity, this problem is at least partially solved. People can build their own accessories to suit their needs, thus eliminating incompatibility and unsuitability of certain types of accessories to certain types of applications.

[Next page](./6_conclusion.md)

*Translated by DeepL.*

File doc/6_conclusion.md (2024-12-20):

# Conclusion

Even after some complications, we can say that the course was smooth. We met all the goals we set, even though we only got the final version as the third prototype. But we take it with a grain of salt, because we know that everything never goes according to plan. In fact, if everything had gone smoothly, then it would have been suspicious.

Scalability and modularity were our main goals for this project. We have created new specific interfaces that, if a rich ecosystem is created, will be of great interest to at least a few students and DIYers around the world. We plan to share this project further and it will be up to the people that whether it takes off.

It is possible that we will use this project for further study. Because this project, if fully understood, has the value of a bachelor's thesis. And there is always something to improve and learn, because biotechnology and connecting biological material with devices is the future. We probably dare not go to study this field, but one has to acknowledge that having a broader outlook is worthwhile.

This project has enriched us more than all the training we have done combined, students should be more and earlier involved in especially the right choice of non-uniform projects. Because only diversity and other "special" practices bring innovation.

[Next page](./7_literature.md)

*Translated by DeepL.*

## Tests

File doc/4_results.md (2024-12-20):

# Results

In the course of putting mental and physical work into this project, there have been minor and major problems. However, we can say with a clear conscience that we have done a great job. It was not easy like the ordinary and much-liked projects we have already done. We often had to look up the theory and methods used ourselves on foreign sources in English. That's why this thesis is also written mainly from our own experience gained in the last half a year. Although a huge amount of theory can be written on the subject of EEG, we decided to take a more concise route.

As far as the device itself is concerned, as has already been written, we did not avoid complications either. The first prototype, although not completely tested, showed signs of functionality, such as communication with a computer and interception of interfering signals. Its biggest problem, however, was its poorly thought out power supply and its cluttered design.

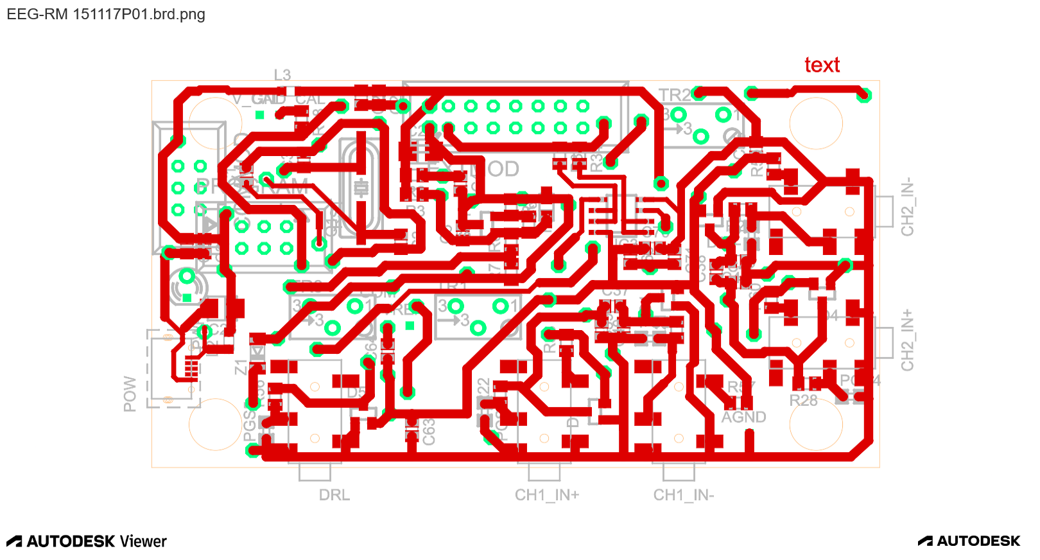
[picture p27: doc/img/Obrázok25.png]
"Top side of the first prototype PCB design" Top side of the first prototype PCB design


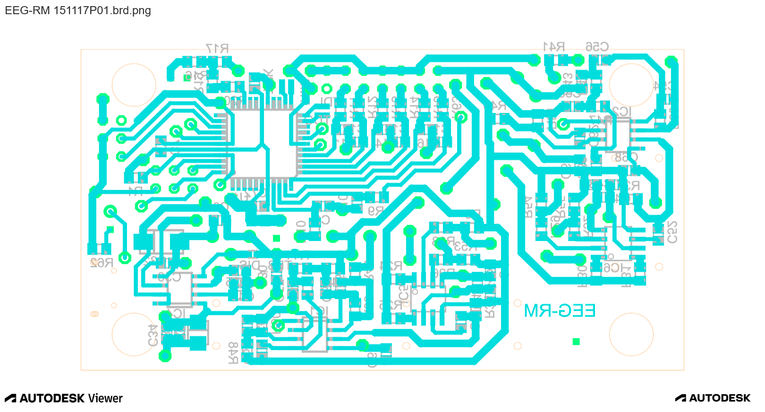
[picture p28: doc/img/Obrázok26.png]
"Bottom side of the first prototype PCB design" Bottom side of the first prototype PCB design


"First prototype PCB design" First prototype PCB design

We produced the electrodes before the actual production of the second prototype with incompatible wiring for the first prototype. Therefore, we had to produce the second one urgently.

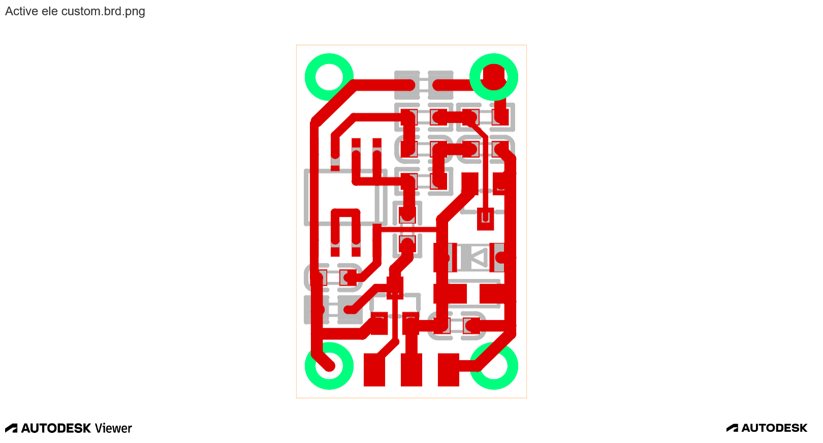
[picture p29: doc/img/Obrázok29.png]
"Active electrode PCB design" Active electrode PCB design


"Active electrode with contact and active part" Active electrode with contact and active part

In the second prototype of the first version, we tried to make it more refined, simpler and clearer. However, this turned into even more serious problems. Diodes in short circuit and rotated operational amplifier. That's why we started to wonder if we shouldn't make a third prototype straight away, as we found a lot more problems than we had anticipated. However, the updated second prototype fixed the diode design and should be working smoothly. Despite this, we decided to invest some time improving and making the overall design a bit neater.

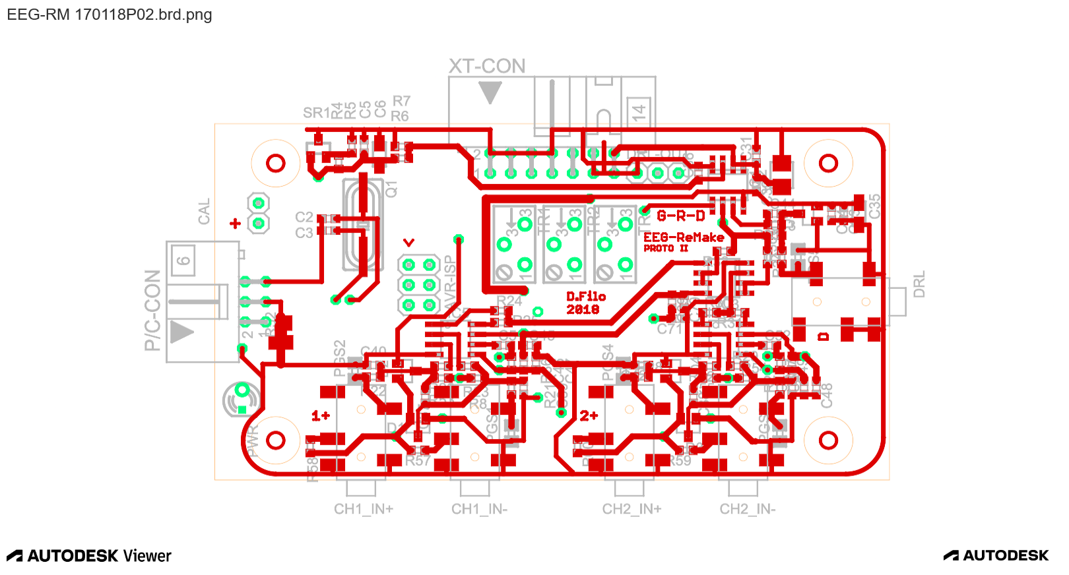
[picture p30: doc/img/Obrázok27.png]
"Top side of the second prototype PCB design" Top side of the second prototype PCB design


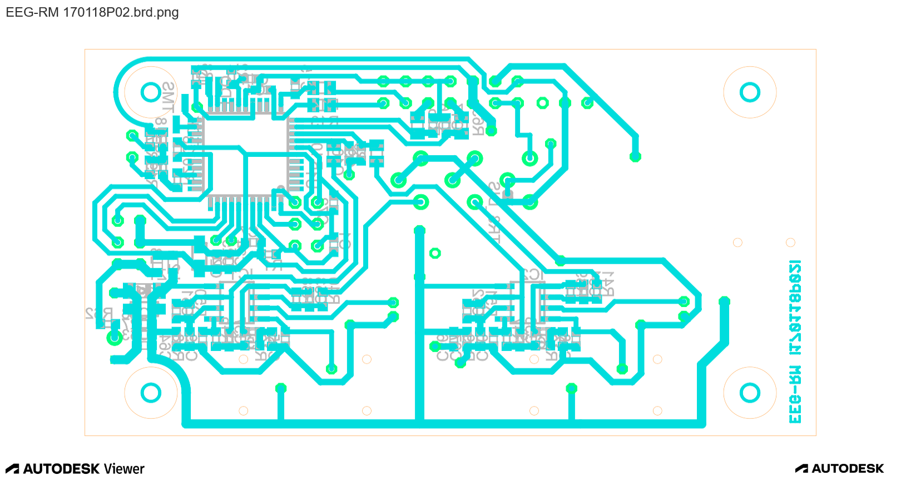
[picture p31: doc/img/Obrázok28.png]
"Bottom side of the second prototype PCB design" Bottom side of the second prototype PCB design


"Front side of Prototype 2 PCB" Front side of Prototype 2 PCB

"Back side of Prototype 2 PCB" Back side of Prototype 2 PCB

"Front side of Prototype 2 PCB with components soldered on" Front side of Prototype 2 PCB with components soldered on

"Back side of Prototype 2 PCB with components soldered on" Back side of Prototype 2 PCB with components soldered on

The third prototype integrates the seamless use of fewer channels while maintaining the functionality of the DRL. This is an excellent improvement over the second prototype. It further focuses on cosmetic and functional adjustments to the layout of the components.

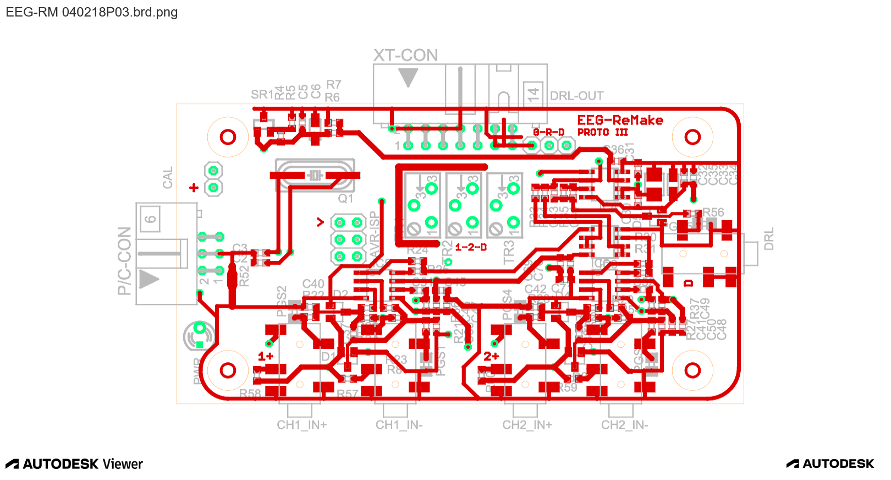
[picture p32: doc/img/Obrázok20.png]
"Top view of prototype 3 PCB" Top view of prototype 3 PCB


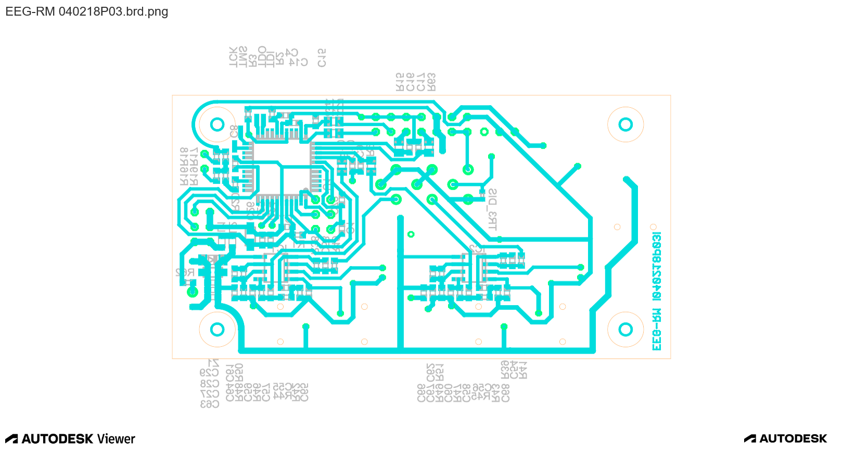
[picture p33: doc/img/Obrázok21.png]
"Bottom view of prototype 3 PCB" Bottom view of prototype 3 PCB


"Front side of Prototype 3 PCB with components soldered on" Front side of Prototype 3 PCB with components soldered on

"Back side of Prototype 3 PCB with components soldered on" Back side of Prototype 3 PCB with components soldered on

Hoping that the third prototype will be the final version, we decided to produce a P/C module for isolated communication and power supply via USB. We managed to produce the module without any problems and the next logical step is to create a 3D printable box for it.

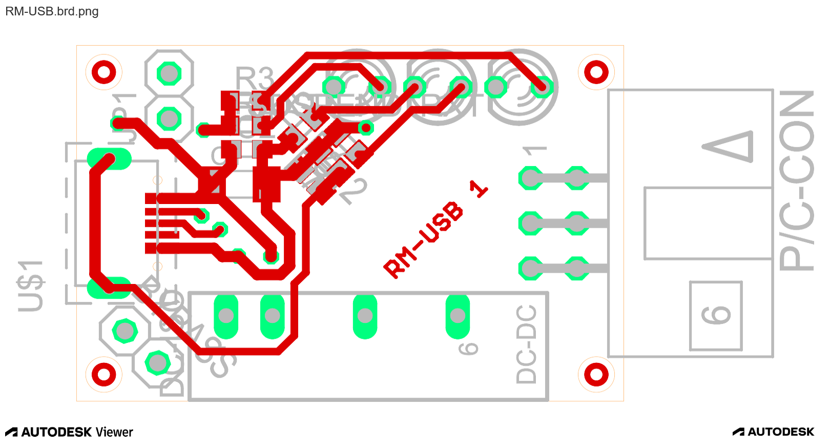
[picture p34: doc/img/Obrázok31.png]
"Top view of RM-USB P/C module PCB design" Top view of RM-USB P/C module PCB design


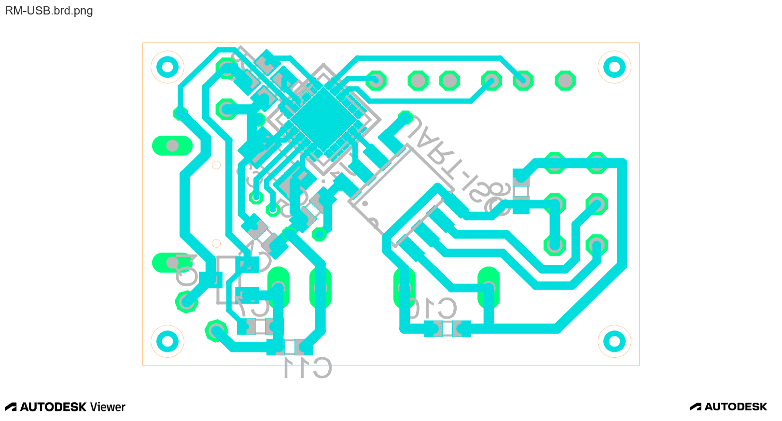
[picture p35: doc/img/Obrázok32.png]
"Bottom view of RM-USB P/C module PCB design" Bottom view of RM-USB P/C module PCB design


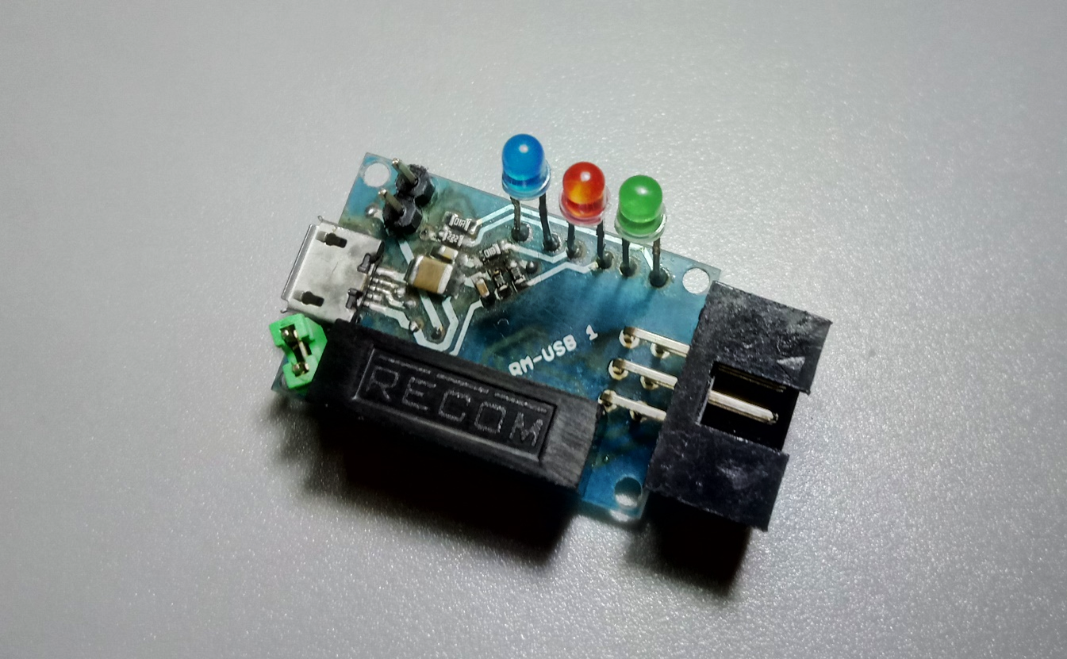
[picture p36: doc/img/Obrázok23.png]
"P/C USB UART module version 1 top side" P/C USB UART module version 1 top side


"P/C USB UART module version 1 bottom side" P/C USB UART module version 1 bottom side

[Next page](./5_discussion.md)

*Translated by DeepL.*

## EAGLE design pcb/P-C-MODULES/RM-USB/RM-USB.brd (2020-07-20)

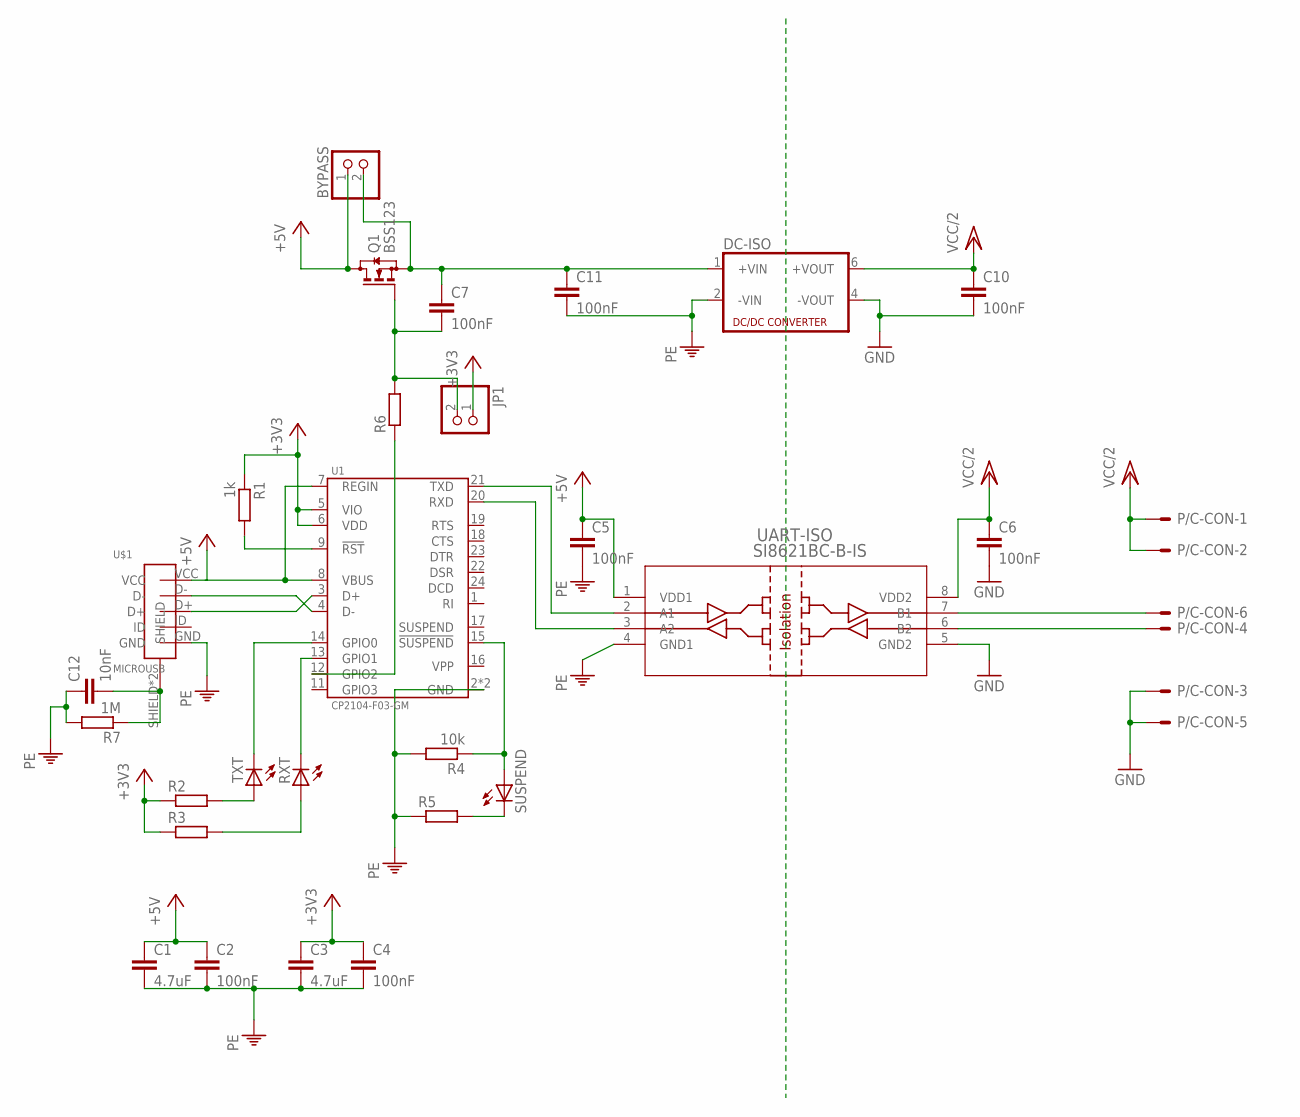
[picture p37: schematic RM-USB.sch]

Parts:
BYPASS: PINHD-1X2; 1X02
C1, C3: 4.7uF; C1206K
C2, C4, C5, C6, C7, C10, C11: 100nF; C0603
C12: 10nF; C0603
DC-ISO: NMA
JP1: PINHD-1X2; 1X02
P/C-CON: ML6EL; ML6L
Q1: BSS123; SOT23
R1: 1k; R0603
R2, R3, R5, R6: R-EU_R0603; R0603
R4: 10k; R0603
R7: 1M; R0603
RXT: LED3MM
SUSPEND: LED3MM
TXT: LED3MM
U1: CP2104-F03-GM; QFN-24-4X4
U$1: MICROUSB
UART-ISO: SI8621BC-B-IS; SOIC-8

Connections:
+3V3: C3.1, C4.1, JP1.1, R1.1, R2.1, R3.1, U1.5 (VIO), U1.6 (VDD)
+5V: BYPASS.1, C1.1, C2.1, C5.1, Q1.3 (D), U1.7 (REGIN), U1.8 (VBUS), U$1.VCC, UART-ISO.1 (VDD1)
GND: C6.2, C10.2, DC-ISO.4 (-VOUT), P/C-CON.3, P/C-CON.5, UART-ISO.5 (GND2)
unnamed: U1.4 (D-), U$1.D-
unnamed: U1.3 (D+), U$1.D+
unnamed: R1.2, U1.9 (!RST)
unnamed: R3.2, RXT.A
unnamed: TXT.K (C), U1.14 (GPIO0)
unnamed: RXT.K (C), U1.13 (GPIO1)
unnamed: R2.2, TXT.A
unnamed: U1.21 (TXD), UART-ISO.2 (A1)
unnamed: U1.20 (RXD), UART-ISO.3 (A2)
unnamed: P/C-CON.4, UART-ISO.6 (B2)
unnamed: P/C-CON.6, UART-ISO.7 (B1)
unnamed: R4.1, SUSPEND.A, U1.15 (!SUSPEND)
unnamed: BYPASS.2, C7.1, C11.1, DC-ISO.1 (+VIN), Q1.2 (S)
unnamed: R5.2, SUSPEND.K (C)
unnamed: C7.2, JP1.2, Q1.1 (G), R6.2
unnamed: C12.2, R7.1, U$1.SHIELD, U$1.SHIELD1 (SHIELD)
unnamed: R6.1, U1.12 (GPIO2)
PE: C1.2, C2.2, C3.2, C4.2, C5.2, C11.2, C12.1, DC-ISO.2 (-VIN), R4.2, R5.1, R7.2, U1.2 (GND), U1.PAD (GND), U$1.GND, UART-ISO.4 (GND1)
VCC/2: C6.1, C10.1, DC-ISO.6 (+VOUT), P/C-CON.1, P/C-CON.2, UART-ISO.8 (VDD2)

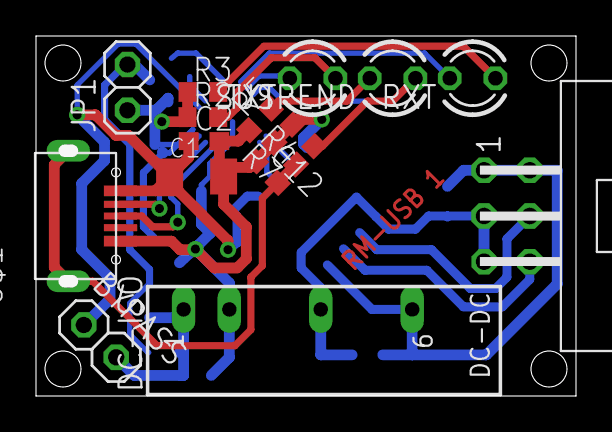
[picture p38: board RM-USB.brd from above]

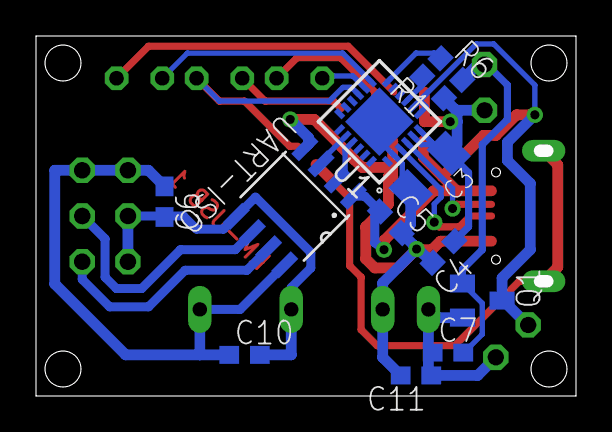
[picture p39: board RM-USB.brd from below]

Board: 2 copper layers, 30.0 x 20.0 mm, 28 parts (12 on the bottom side), 22 nets.

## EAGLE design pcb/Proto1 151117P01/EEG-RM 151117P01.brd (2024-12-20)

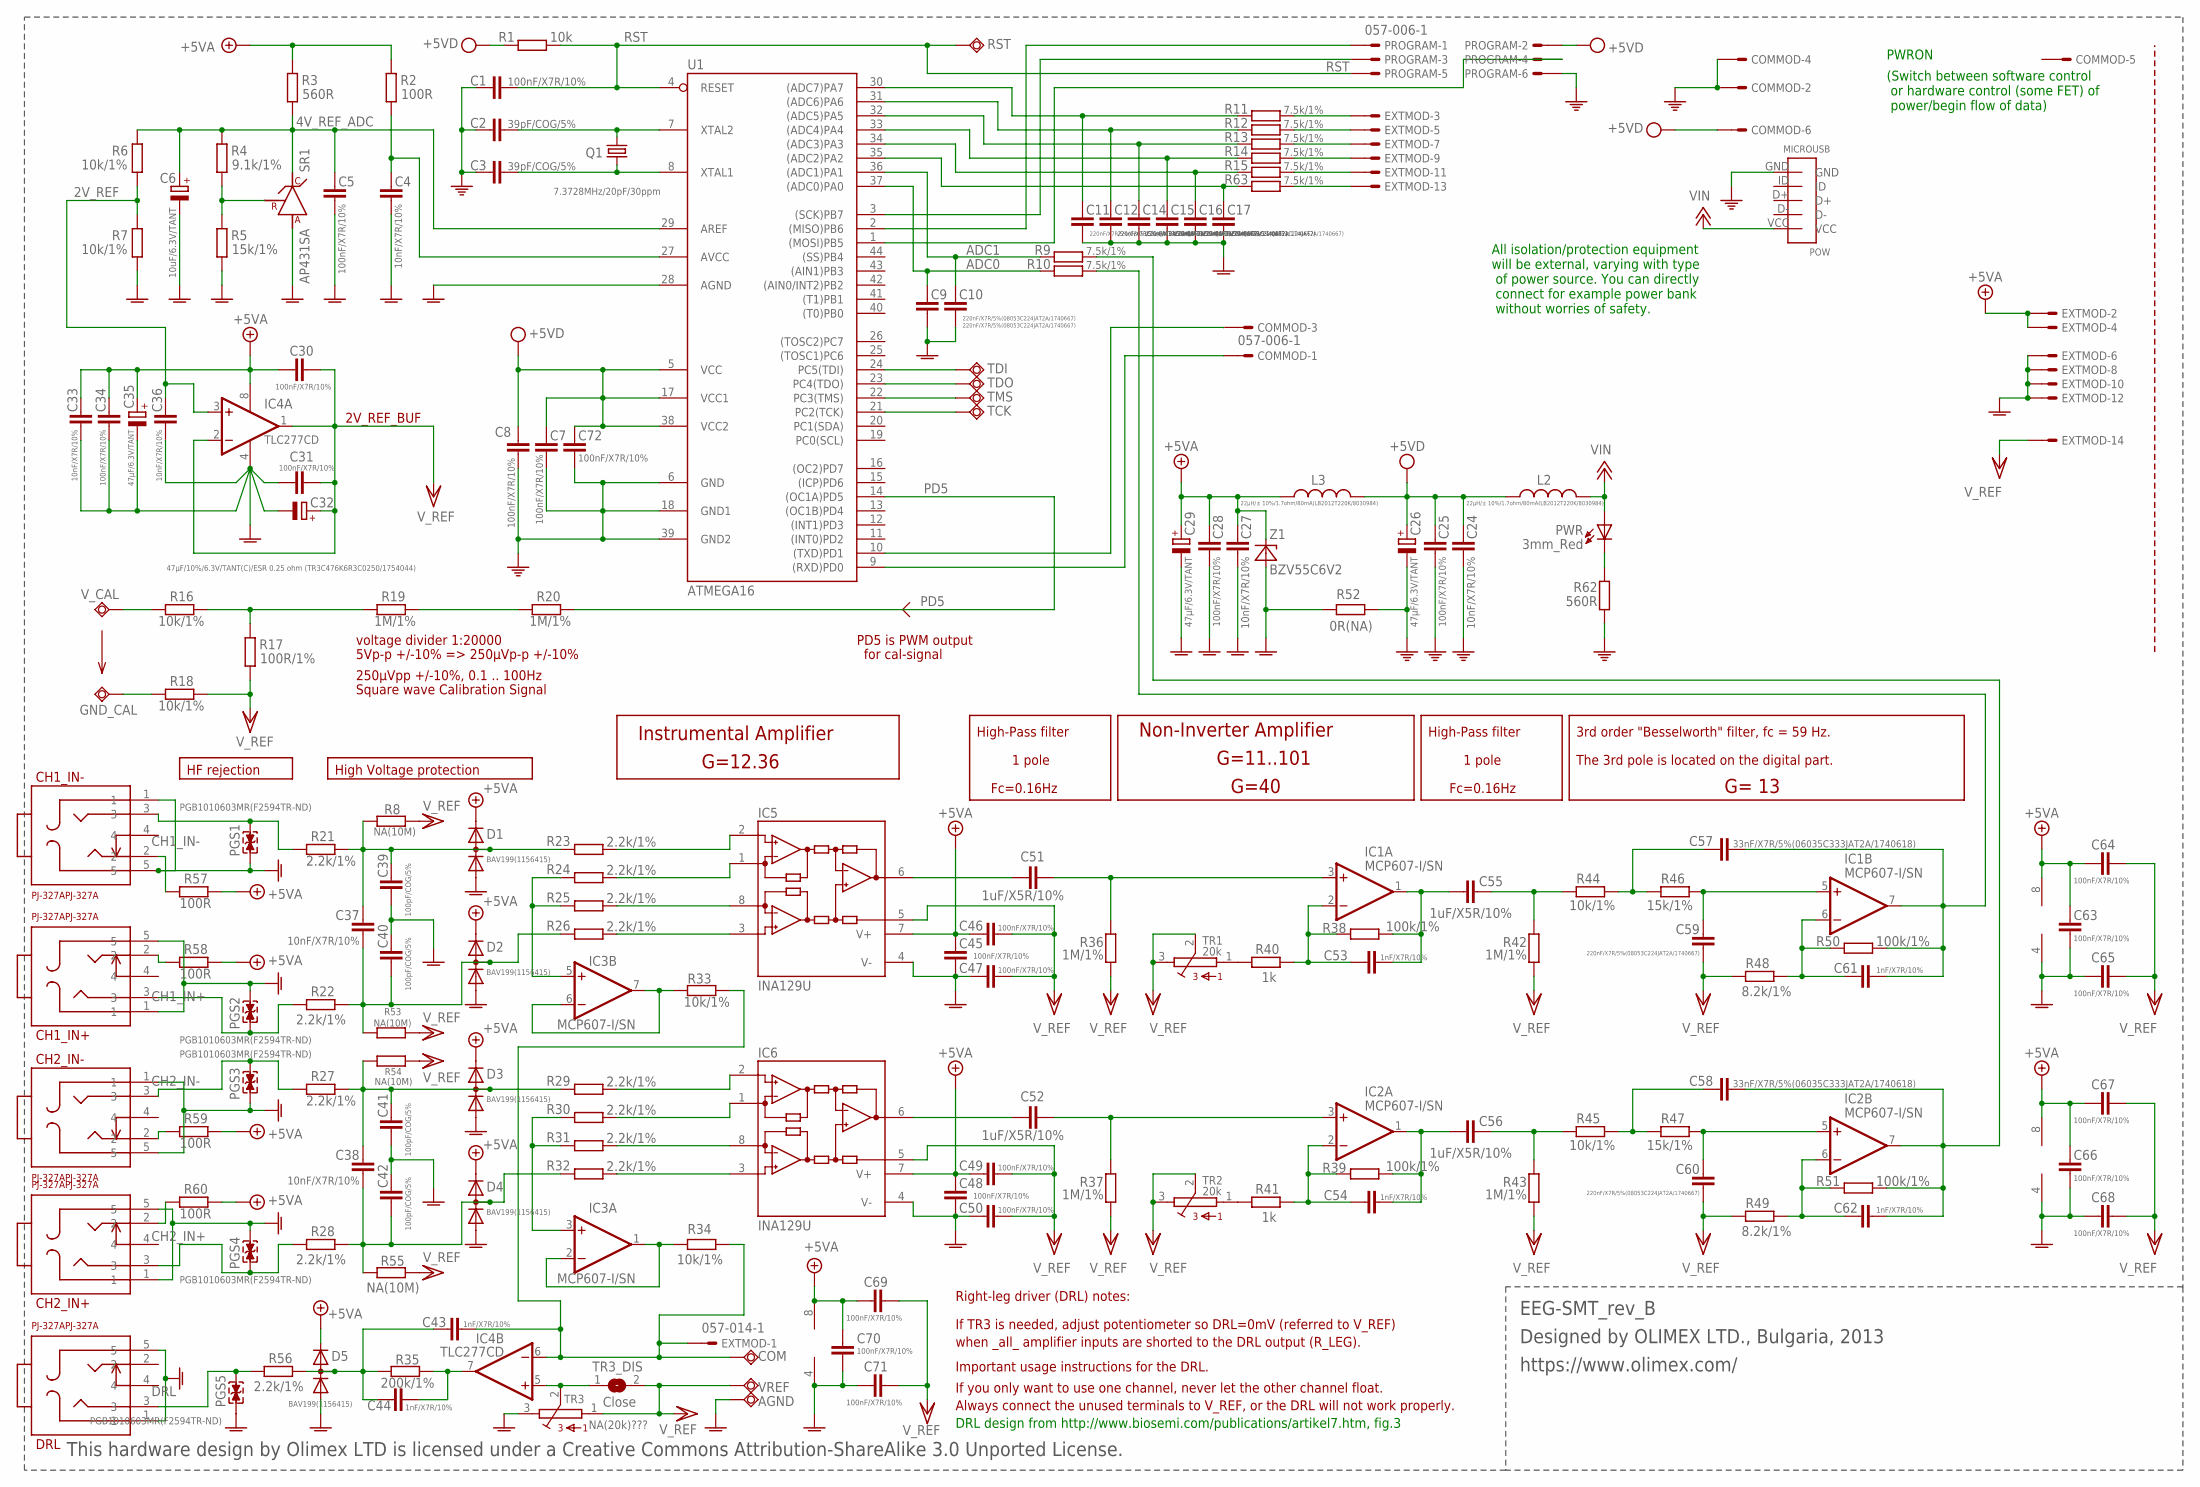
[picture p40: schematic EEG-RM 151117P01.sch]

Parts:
AGND: TESTPAD3; TEST_PAD40/70/SQUARE
C1, C5, C7, C8, C25, C28, C30, C31, C34, C45, C46, C47, C48, C49, C50, C63, C64, C65, C66, C67, C68, C69, C70, C71, C72: 100nF/X7R/10%; C2012
C2, C3: 39pF/COG/5%; C2012
C4, C24, C27, C33, C36, C37, C38: 10nF/X7R/10%; C2012
C6: 10uF/6.3V/TANT; CT3216
C9, C10, C11, C12, C14, C15, C16, C17, C59, C60: 220nF/X7R/5%(08053C224JAT2A/1740667); C2012
C26, C29, C35: 47µF/6.3V/TANT; CT3528
C32: 47µF/10%/6.3V/TANT(C)/ESR 0.25 ohm (TR3C476K6R3C0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; CT6032
C39, C40, C41, C42: 100pF/COG/5%; C2012
C43, C44, C53, C54, C61, C62: 1nF/X7R/10%; C2012
C51, C52, C55, C56: 1uF/X5R/10%; C2012
C57, C58: 33nF/X7R/5%(06035C333JAT2A/1740618); C2012
CH1_IN+, CH1_IN-, CH2_IN+, CH2_IN-: PJ-327APJ-327A; PJ-327A
COM: TESTPAD3; TEST_PAD40/70/SQUARE
COMMOD: 057-006-1
D1, D2, D3, D4, D5: BAV199(1156415); SOT23C(BAT54S)
DRL: PJ-327APJ-327A; PJ-327A
EXTMOD: 057-014-1
GND_CAL: TESTPAD3; TEST_PAD40/70/SQUARE
IC1, IC2, IC3: MCP607-I/SN; SO08
IC4: TLC277CD; SO08
IC5, IC6: INA129U; SO08
L2, L3: 22µH/± 10%/1.7ohm/80mA(LB2012T220K/8030984); L2012C
PGS1, PGS2, PGS3, PGS4, PGS5: PGB1010603MR(F2594TR-ND); 0603
POW: MICROUSB
PROGRAM: 057-006-1
PWR: 3mm_Red; LED-3.0MM
Q1: 7.3728MHz/20pF/30ppm; HC49/SMD2_THIN
R1: 10k; M2012
R2, R57, R58, R59, R60: 100R; M2012
R3, R62: 560R; M2012
R4: 9.1k/1%; M2012
R5, R46, R47: 15k/1%; M2012
R6, R7, R16, R18, R33, R34, R44, R45: 10k/1%; M2012
R8, R53, R54, R55: NA(10M); M2012
R9, R10, R11, R12, R13, R14, R15, R63: 7.5k/1%; M2012
R17: 100R/1%; M2012
R19, R20, R36, R37, R42, R43: 1M/1%; M2012
R21, R22, R23, R24, R25, R26, R27, R28, R29, R30, R31, R32, R56: 2.2k/1%; M2012
R35: 200k/1%; M2012
R38, R39, R50, R51: 100k/1%; M2012
R40, R41: 1k; M2012
R48, R49: 8.2k/1%; M2012
R52: 0R(NA); M2012
RST: TESTPAD80/30; SMD80/30
SR1: AP431SA; SOT-23
TCK: TESTPAD80/30; SMD80/30
TDI: TESTPAD80/30; SMD80/30
TDO: TESTPAD80/30; SMD80/30
TMS: TESTPAD80/30; SMD80/30
TR1, TR2: 20k; S64Y
TR3: NA(20k)???; S64Y
TR3_DIS: Close; SJ_1_SMALLER
U1: ATMEGA16; 44TQFP
VREF: TESTPAD3; TEST_PAD40/70/SQUARE
V_CAL: TESTPAD3; TEST_PAD40/70/SQUARE
Z1: BZV55C6V2; MINI-MELF

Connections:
2V_REF: C36.1, IC4.3 (+IN), R6.1, R7.2
4V_REF_ADC: C5.1, C6.+, R3.1, R4.2, R6.2, SR1.1 (C), U1.29 (AREF)
+5V: C27.1, C28.1, C29.+, C30.2, C33.1, C34.1, C35.+, C45.1, C46.1, C48.1, C49.1, C63.1, C64.1, C66.1, C67.1, C69.1, C70.1, D1.2 (K), D2.2 (K), D3.2 (K), D4.2 (K), D5.2 (K), EXTMOD.2, EXTMOD.4, IC1.8 (V+), IC2.8 (V+), IC3.8 (V+), IC4.8 (V+), IC5.7 (V+), IC6.7 (V+), L3.2, R2.2, R3.2, R57.2, R58.2, R59.2, R60.2, Z1.1 (C)
+12V: L2.1, POW.VCC, PWR.A
ADC0: C9.1, R10.1, U1.37 ((ADC0)PA0)
ADC1: C10.1, R9.1, U1.36 ((ADC1)PA1)
CH1_IN+: CH1_IN+.3, PGS2.1, R22.1
CH1_IN-: CH1_IN-.3, PGS1.2, R21.1
CH2_IN+: CH2_IN+.3, PGS4.1, R28.1
CH2_IN-: CH2_IN-.3, PGS3.2, R27.1
DRL: DRL.3, PGS5.2, R56.1
GNDA: AGND.P$1, C4.2, C5.2, C6.-, C9.2, C10.2, C11.2, C12.2, C14.2, C15.2, C16.2, C17.2, C27.2, C28.2, C29.-, C31.2, C32.-, C33.2, C34.2, C35.-, C36.2, C39.1, C40.2, C41.1, C42.2, C45.2, C47.1, C48.2, C50.1, C63.2, C65.1, C66.2, C68.1, C70.2, C71.1, CH1_IN+.1, CH1_IN+.5, CH1_IN-.1, CH1_IN-.5, CH2_IN+.1, CH2_IN+.5, CH2_IN-.1, CH2_IN-.5, D1.1 (A), D2.1 (A), D3.1 (A), D4.1 (A), D5.1 (A), DRL.1, DRL.5, EXTMOD.6, EXTMOD.8, EXTMOD.10, EXTMOD.12, IC1.4 (V-), IC2.4 (V-), IC3.4 (V-), IC4.4 (V-), IC5.4 (V-), IC6.4 (V-), PGS1.1, PGS2.2, PGS3.1, PGS4.2, PGS5.1, R5.1, R7.1, R52.1, SR1.3 (A), TR3.3, U1.28 (AGND), Z1.2 (A)
unnamed: CH1_IN-.2, R57.1
unnamed: CH1_IN+.2, R58.1
unnamed: TDI.P$1, U1.24 (PC5(TDI))
unnamed: TDO.P$1, U1.23 (PC4(TDO))
unnamed: TMS.P$1, U1.22 (PC3(TMS))
unnamed: TCK.P$1, U1.21 (PC2(TCK))
unnamed: CH2_IN-.2, R59.1
unnamed: C43.2, C44.2, D5.3 (AK), R35.1, R56.2
unnamed: CH2_IN+.2, R60.1
unnamed: PROGRAM.1, U1.2 ((MISO)PB6)
unnamed: PROGRAM.3, U1.3 ((SCK)PB7)
unnamed: PWR.K (C), R62.2
unnamed: PROGRAM.4, U1.1 ((MOSI)PB5)
unnamed: EXTMOD.3, R11.2
unnamed: C11.1, R11.1, U1.30 ((ADC7)PA7)
unnamed: C12.1, R12.1, U1.31 ((ADC6)PA6)
unnamed: EXTMOD.5, R12.2
unnamed: C4.1, R2.1, U1.27 (AVCC)
unnamed: R4.1, R5.2, SR1.2 (R)
unnamed: COMMOD.3, U1.10 ((TXD)PD1)
unnamed: COMMOD.1, U1.9 ((RXD)PD0)
unnamed: C17.1, R63.1, U1.35 ((ADC2)PA2)
unnamed: C16.1, R15.1, U1.34 ((ADC3)PA3)
unnamed: C3.1, Q1.2, U1.8 (XTAL1)
unnamed: C2.1, Q1.1, U1.7 (XTAL2)
unnamed: R40.2, TR1.1
unnamed: R41.2, TR2.1
unnamed: EXTMOD.11, R15.2
unnamed: EXTMOD.13, R63.2
unnamed: EXTMOD.7, R13.2
unnamed: EXTMOD.9, R14.2
unnamed: C14.1, R13.1, U1.32 ((ADC5)PA5)
unnamed: C15.1, R14.1, U1.33 ((ADC4)PA4)
unnamed: C55.2, R42.1, R44.1
unnamed: C51.1, IC5.6 (OUT)
unnamed: IC5.2 (-IN), R23.1
unnamed: IC5.1 (RG), R24.1
unnamed: C37.1, C40.1, D2.3 (AK), R22.2, R26.2, R53.2
unnamed: C37.2, C39.2, D1.3 (AK), R8.2, R21.2, R23.2
unnamed: C38.1, C42.1, D4.3 (AK), R28.2, R32.2, R55.2
unnamed: C38.2, C41.2, D3.3 (AK), R27.2, R29.2, R54.2
unnamed: IC5.8 (RG), R25.1
unnamed: C51.2, IC1.3 (+IN), R36.1
unnamed: IC3.5 (+IN), R24.2, R25.2
unnamed: C53.2, C55.1, IC1.1 (OUT), R38.2
unnamed: C53.1, IC1.2 (-IN), R38.1, R40.1
unnamed: IC5.3 (+IN), R26.1
unnamed: C59.1, IC1.5 (+IN), R46.2
unnamed: C57.1, R44.2, R46.1
unnamed: C57.2, C61.2, IC1.7 (OUT), R10.2, R50.2
unnamed: C61.1, IC1.6 (-IN), R48.1, R50.1
unnamed: C52.2, IC2.3 (+IN), R37.1
unnamed: C54.2, C56.1, IC2.1 (OUT), R39.2
unnamed: C54.1, IC2.2 (-IN), R39.1, R41.1
unnamed: C60.1, IC2.5 (+IN), R47.2
unnamed: C58.1, R45.2, R47.1
unnamed: C58.2, C62.2, IC2.7 (OUT), R9.2, R51.2
unnamed: C62.1, IC2.6 (-IN), R49.1, R51.1
unnamed: C56.2, R43.1, R45.1
unnamed: C52.1, IC6.6 (OUT)
unnamed: IC6.1 (RG), R30.1
unnamed: IC6.8 (RG), R31.1
unnamed: IC3.3 (+IN), R30.2, R31.2
unnamed: IC6.2 (-IN), R29.1
unnamed: IC6.3 (+IN), R32.1
unnamed: IC3.1 (OUT), IC3.2 (-IN), R34.2
unnamed: IC3.6 (-IN), IC3.7 (OUT), R33.2
unnamed: IC4.5 (+IN), TR3.2, TR3_DIS.1
unnamed: C44.1, IC4.7 (OUT), R35.2
unnamed: R19.2, R20.1
unnamed: C43.1, COM.P$1, EXTMOD.1, IC4.6 (-IN), R33.1, R34.1
unnamed: R16.2, R17.2, R19.1
unnamed: R16.1, V_CAL.P$1
unnamed: GND_CAL.P$1, R18.1
PD5: R20.2, U1.14 ((OC1A)PD5)
PE: C1.2, C2.2, C3.2, C7.2, C8.2, C24.2, C25.2, C26.-, C72.2, COMMOD.2, COMMOD.4, POW.GND, PROGRAM.6, R52.2, R62.1, U1.6 (GND), U1.18 (GND1), U1.39 (GND2)
RST: C1.1, PROGRAM.5, R1.2, RST.P$1, U1.4 (RESET)
VCC/2: C30.1, C31.1, C32.+, C46.2, C47.2, C49.2, C50.2, C59.2, C60.2, C64.2, C65.2, C67.2, C68.2, C69.2, C71.2, EXTMOD.14, IC4.1 (OUT), IC4.2 (-IN), IC5.5 (REF), IC6.5 (REF), R8.1, R17.1, R18.2, R36.2, R37.2, R42.2, R43.2, R48.2, R49.2, R53.1, R54.1, R55.1, TR1.2, TR1.3, TR2.2, TR2.3, TR3.1, TR3_DIS.2, VREF.P$1
VPP: C7.1, C8.1, C24.1, C25.1, C26.+, C72.1, COMMOD.6, L2.2, L3.1, PROGRAM.2, R1.1, U1.5 (VCC), U1.17 (VCC1), U1.38 (VCC2)

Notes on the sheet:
PD5 is PWM output
for cal-signal
250µVpp +/-10%, 0.1 .. 100Hz
Square wave Calibration Signal
voltage divider 1:20000
G=40
G=11..101
5Vp-p +/-10% => 250µVp-p +/-10%
3rd order "Besselworth" filter, fc = 59 Hz.
The 3rd pole is located on the digital part.
Fc=0.16Hz
HF rejection
High Voltage protection
High-Pass filter
Non-Inverter Amplifier
G= 13
1 pole
G=12.36
2V_REF_BUF
Instrumental Amplifier
DRL design from http://www.biosemi.com/publications/artikel7.htm, fig.3
If TR3 is needed, adjust potentiometer so DRL=0mV (referred to V_REF)
when _all_ amplifier inputs are shorted to the DRL output (R_LEG).
If you only want to use one channel, never let the other channel float.
Important usage instructions for the DRL.
Always connect the unused terminals to V_REF, or the DRL will not work properly.
Right-leg driver (DRL) notes:
This hardware design by Olimex LTD is licensed under a Creative Commons Attribution-ShareAlike 3.0 Unported License.
Designed by OLIMEX LTD., Bulgaria, 2013
https://www.olimex.com/
EEG-SMT_rev_B
PWRON
(Switch between software control or hardware control (some FET) of power/begin flow of data)
All isolation/protection equipment will be external, varying with type of power source. You can directly connect for example power bank without worries of safety.

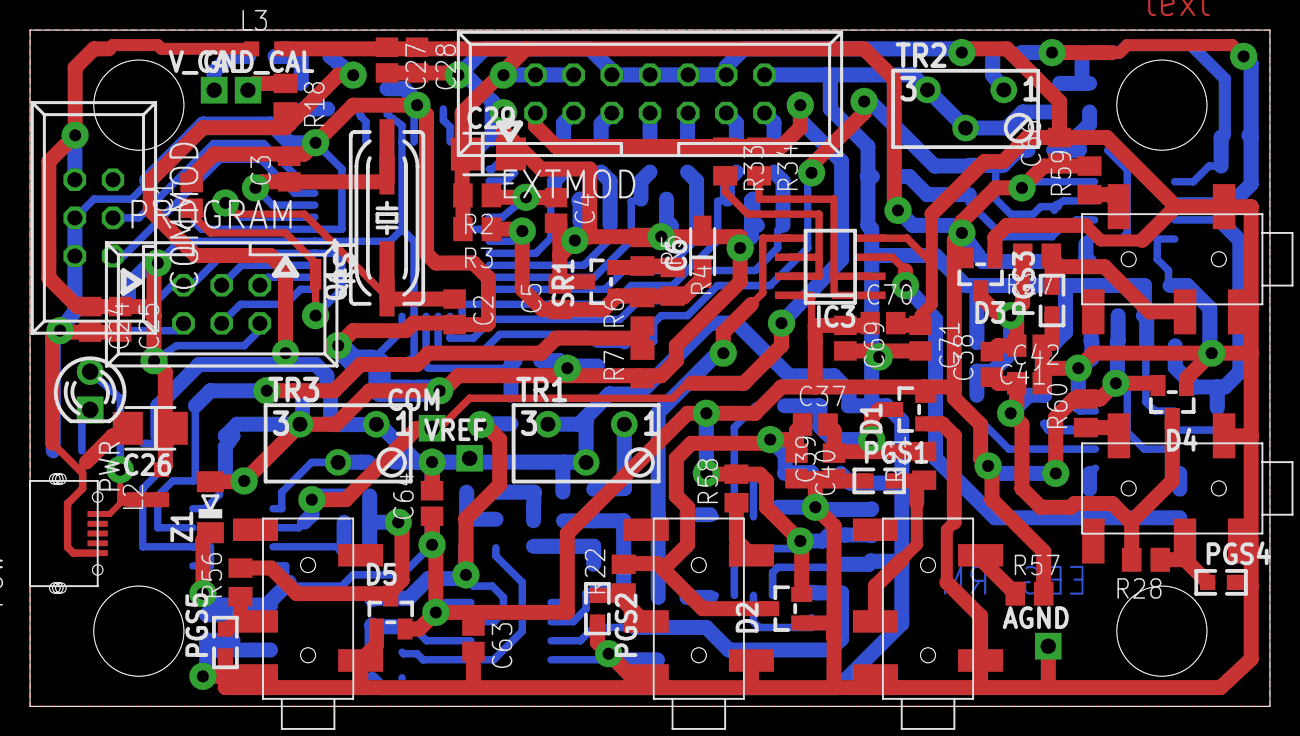
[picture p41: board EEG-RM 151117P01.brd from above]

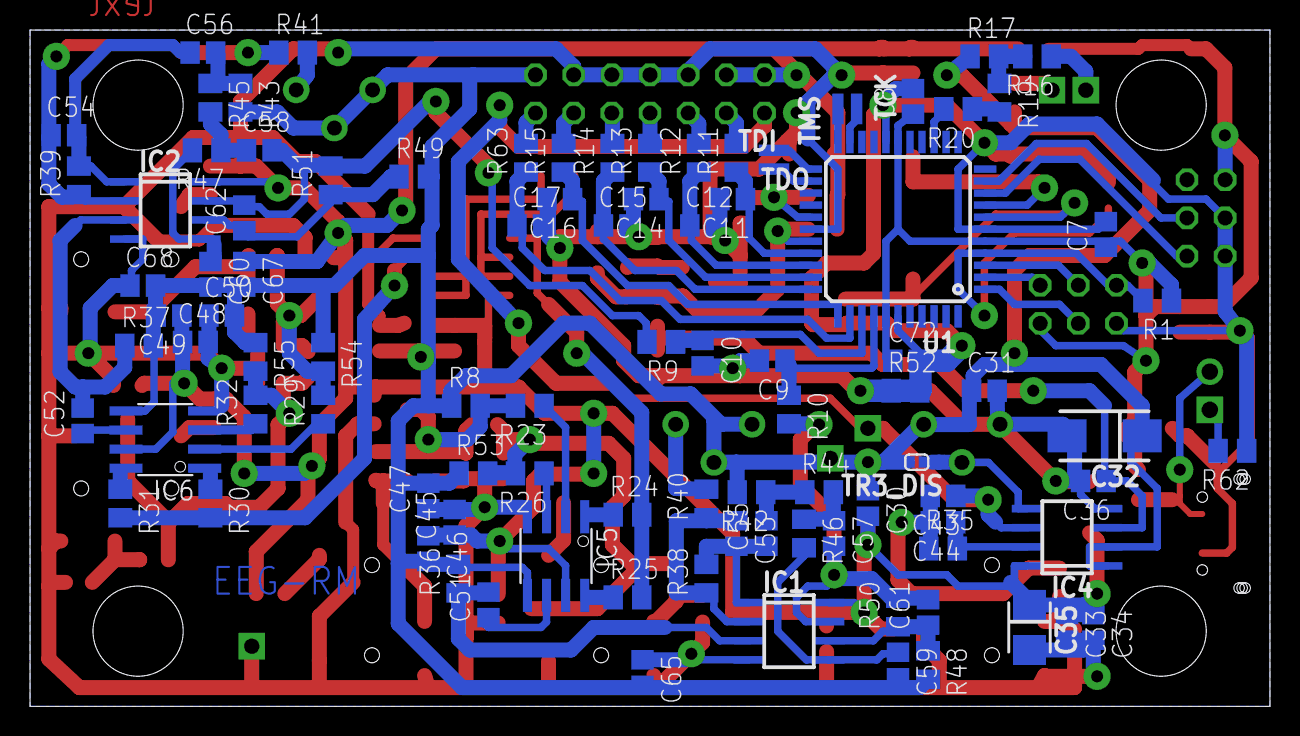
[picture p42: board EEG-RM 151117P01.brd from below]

Board: 2 copper layers, 82.5 x 45.0 mm, 173 parts (96 on the bottom side), 91 nets.

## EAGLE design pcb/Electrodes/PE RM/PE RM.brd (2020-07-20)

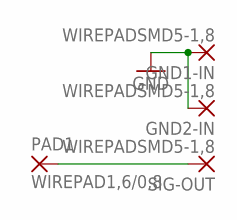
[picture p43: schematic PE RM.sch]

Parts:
GND1-IN, GND2-IN: WIREPADSMD5-1,8; 5-1,8
PAD1: WIREPAD1,6/0,8; 1,6/0,8
SIG-OUT: WIREPADSMD5-1,8; 5-1,8

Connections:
GND: GND1-IN.1, GND2-IN.1
SIG: PAD1.1, SIG-OUT.1

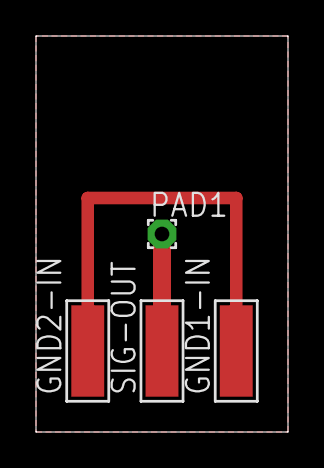
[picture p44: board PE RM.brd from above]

Board: 2 copper layers, 14.0 x 22.0 mm, 4 parts (0 on the bottom side), 2 nets.

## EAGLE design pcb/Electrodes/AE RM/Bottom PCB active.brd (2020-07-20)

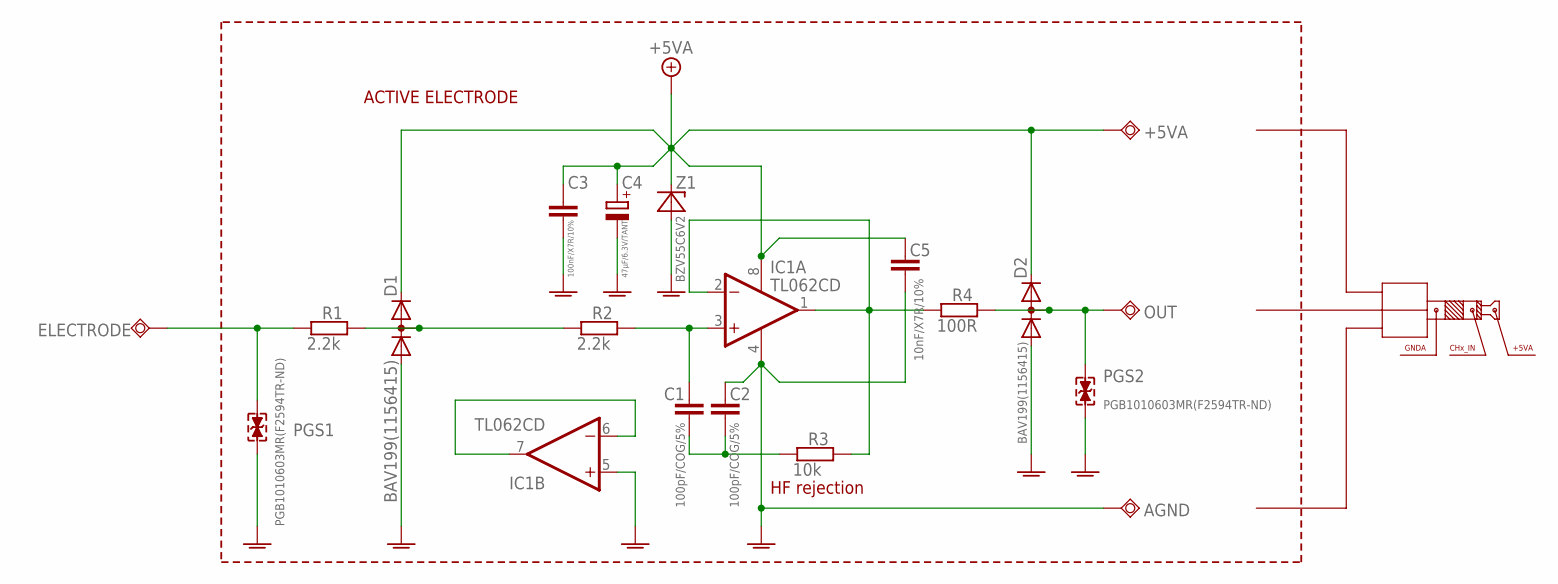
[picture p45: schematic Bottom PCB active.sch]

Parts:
+5VA: TESTPAD80/50; SMD80/50
AGND: TESTPAD80/50; SMD80/50
C1, C2: 100pF/COG/5%; C0603_DWS
C3: 100nF/X7R/10%; C0603_DWS
C4: 47µF/6.3V/TANT; CT3216
C5: 10nF/X7R/10%; C0603_DWS
D1, D2: BAV199(1156415); SOT23C(BAT54S)
ELECTRODE: TESTPAD80/50; SMD80/50
IC1: TL062CD; SO08
OUT: TESTPAD80/50; SMD80/50
PGS1, PGS2: PGB1010603MR(F2594TR-ND); 0603
R1, R2: 2.2k; R0603_5MIL_DWS
R3: 10k; R0603_5MIL_DWS
R4: 100R; R0603_5MIL_DWS
Z1: BZV55C6V2; MINI-MELF

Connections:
+5V: +5VA.P$1, C3.1, C4.+, C5.1, D1.2 (K), D2.2 (K), IC1.8 (V+), Z1.1 (C)
E-OUT: D2.3 (AK), OUT.P$1, PGS2.1, R4.2
ELECTRODE: ELECTRODE.P$1, PGS1.1, R1.1
GNDA: AGND.P$1, C2.2, C3.2, C4.-, C5.2, D1.1 (A), D2.1 (A), IC1.4 (V-), IC1.5 (+IN), PGS1.2, PGS2.2, Z1.2 (A)
unnamed: IC1.6 (-IN), IC1.7 (OUT)
unnamed: IC1.1 (OUT), IC1.2 (-IN), R3.2, R4.1
unnamed: C1.2, IC1.3 (+IN), R2.2
unnamed: C1.1, C2.1, R3.1
unnamed: D1.3 (AK), R1.2, R2.1

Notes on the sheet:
GNDA
CHx_IN
+5VA
ACTIVE ELECTRODE
HF rejection

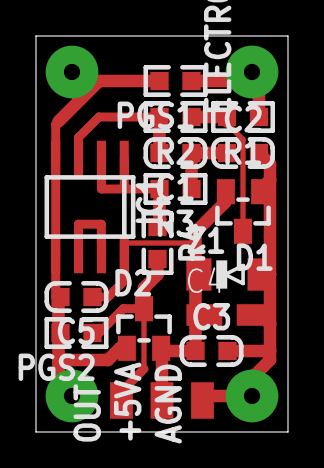
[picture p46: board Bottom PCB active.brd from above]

Board: 2 copper layers, 14.0 x 22.0 mm, 19 parts (0 on the bottom side), 9 nets.

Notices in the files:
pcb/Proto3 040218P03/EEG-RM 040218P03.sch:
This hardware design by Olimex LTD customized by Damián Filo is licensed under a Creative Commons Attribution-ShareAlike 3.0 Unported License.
